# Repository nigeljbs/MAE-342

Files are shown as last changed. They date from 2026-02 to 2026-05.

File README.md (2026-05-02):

<p align="center">
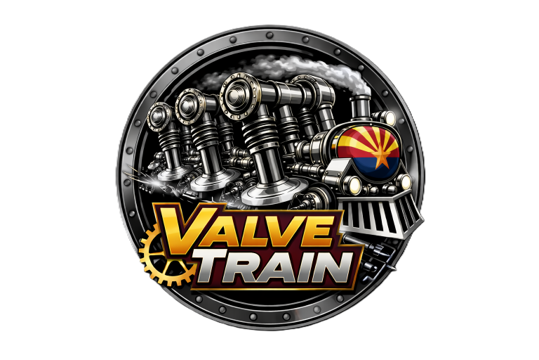
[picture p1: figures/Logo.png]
  
</p>

## Table of Contents
1. [Phase 1: System Understanding & Conceptual Design](Phase_1.md)
   
    [Phase 1 Video](https://youtu.be/j8frhQOj0eA)
2. [Phase 2: Detailed CAD Design & Engineering Analysis](Phase_2.md)
   
    [Phase 2 Video](https://youtu.be/f7b7LyeaBDE)
3. [Phase 3: Prototyping, Testing & Reflection](Phase_3.md)
   
    [Phase 3 Video](https://youtu.be/BKtHc9wmN2A)
4. [References](References.md)

*Please view all reports in a Light Theme*

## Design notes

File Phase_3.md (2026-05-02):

# Phase 3 - Prototyping, Testing & Reflection

<p align="center">
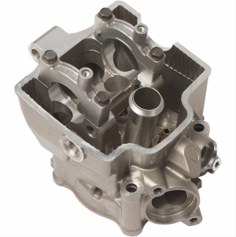
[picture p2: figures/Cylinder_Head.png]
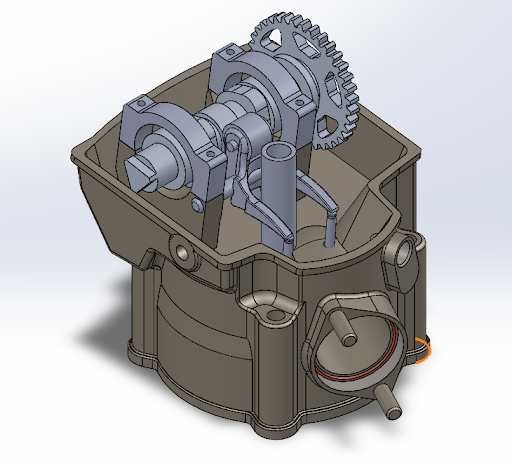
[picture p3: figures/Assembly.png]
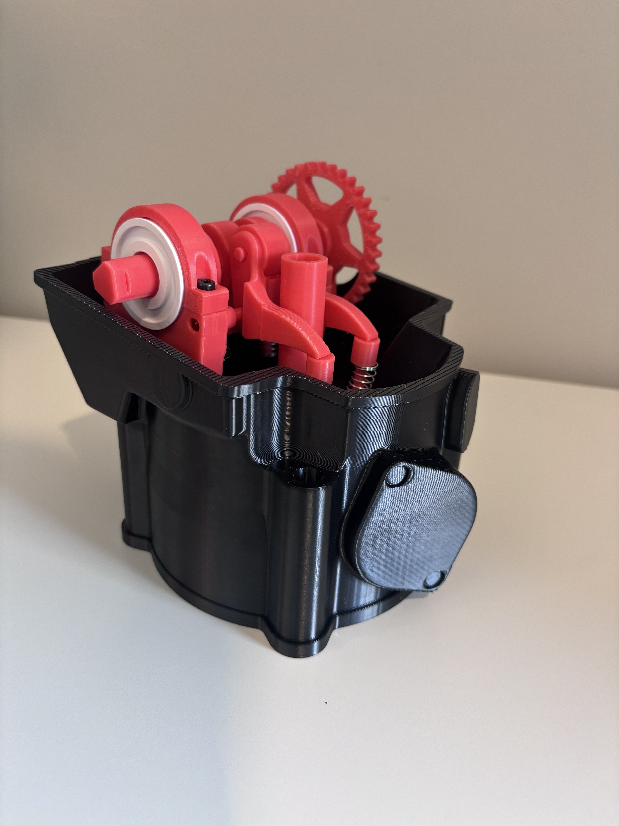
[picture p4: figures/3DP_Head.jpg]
     
</p>

## Fabrication Details
  Our valve train prototype was fabricated using PETG filament, brass threaded inserts, and springs. All 3D components were printed using PETG filament, which was selected for its balance of strength, durability, and ease of printing. A layer height of 0.16 mm, two wall loops, and 15% infill were used to obtain a balance between print efficiency and structural integrity. Supports were incorporated as needed, and the print orientation was strategically selected to maximize strength along primary load-bearing directions. The use of a relatively low infill density was justified by the Phase 2 analysis, which indicated that the system would not be subjected to significant structural loads. The brass threaded inserts and springs were sourced from McMaster-Carr.

<p align="center">
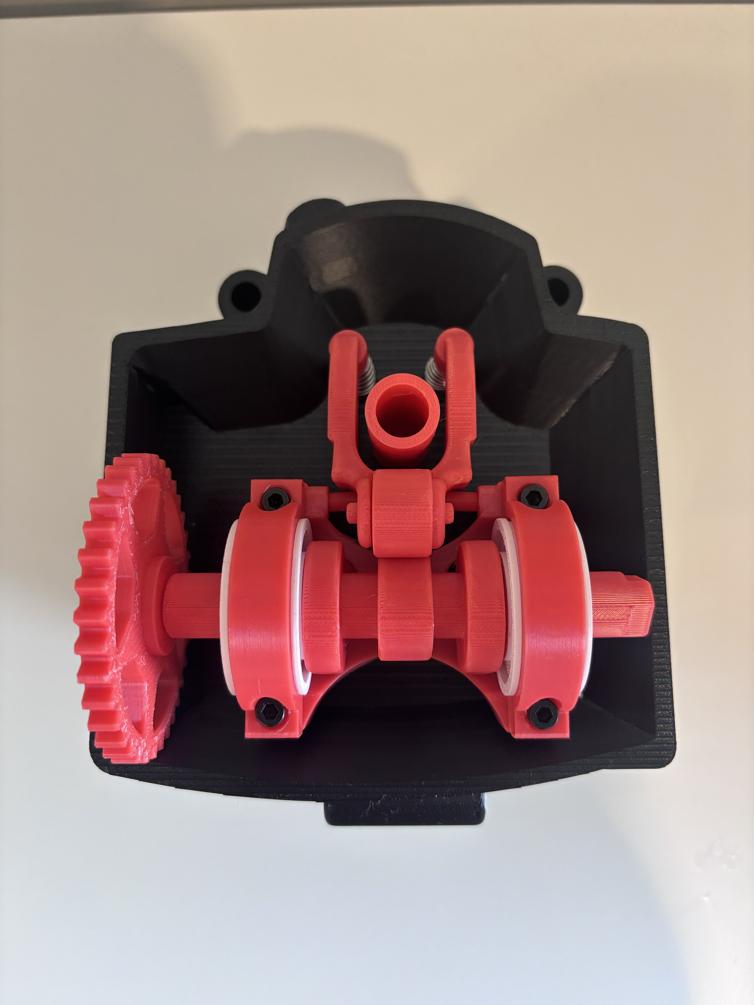
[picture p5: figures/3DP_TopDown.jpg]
  
</p>

## Assembly Procedure 
  The assembly process was completed as follows. The valves were first positioned within the cylinder head, followed by the installation of the valve buckets and springs. The rocker arm and roller were then mounted using pin connections. Finally, the camshaft was positioned in bearings, then the remaining structural components were secured using threaded fasteners. The modular design allowed certain components to be assembled into subassemblies before final integration, thereby reducing overall assembly complexity.
  
<p align="center">
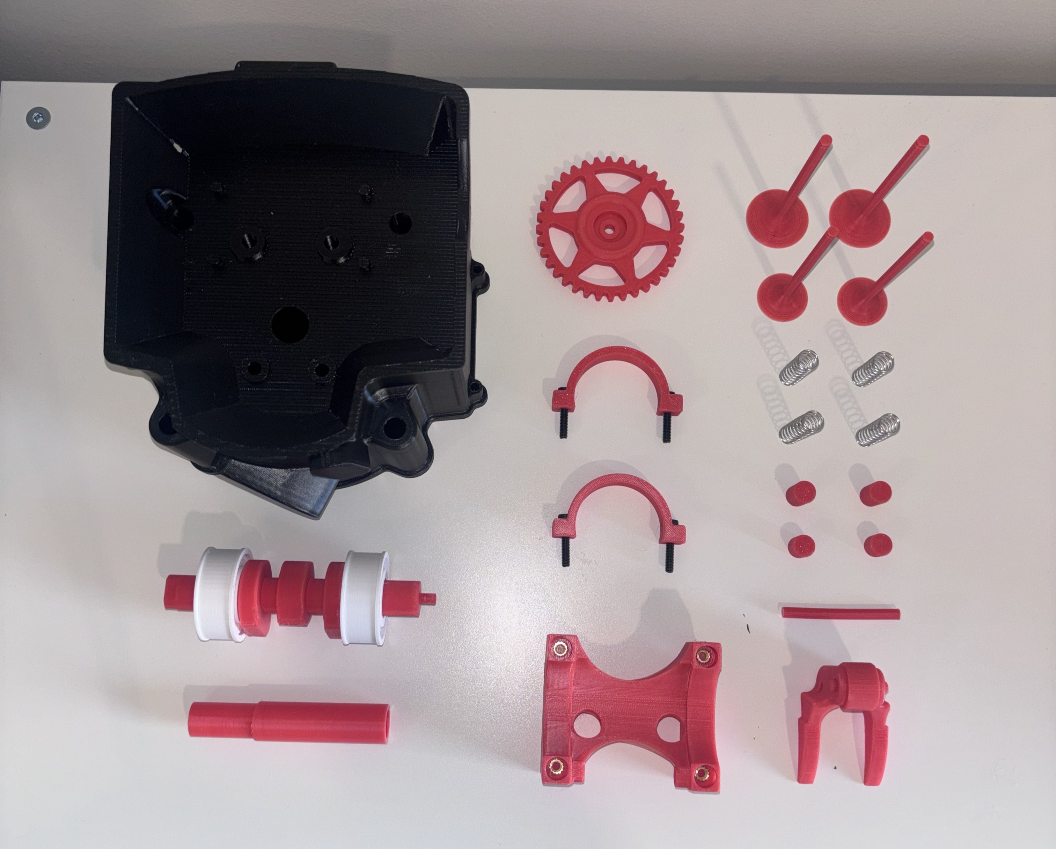
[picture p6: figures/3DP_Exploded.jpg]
  
</p>

<p align="center">
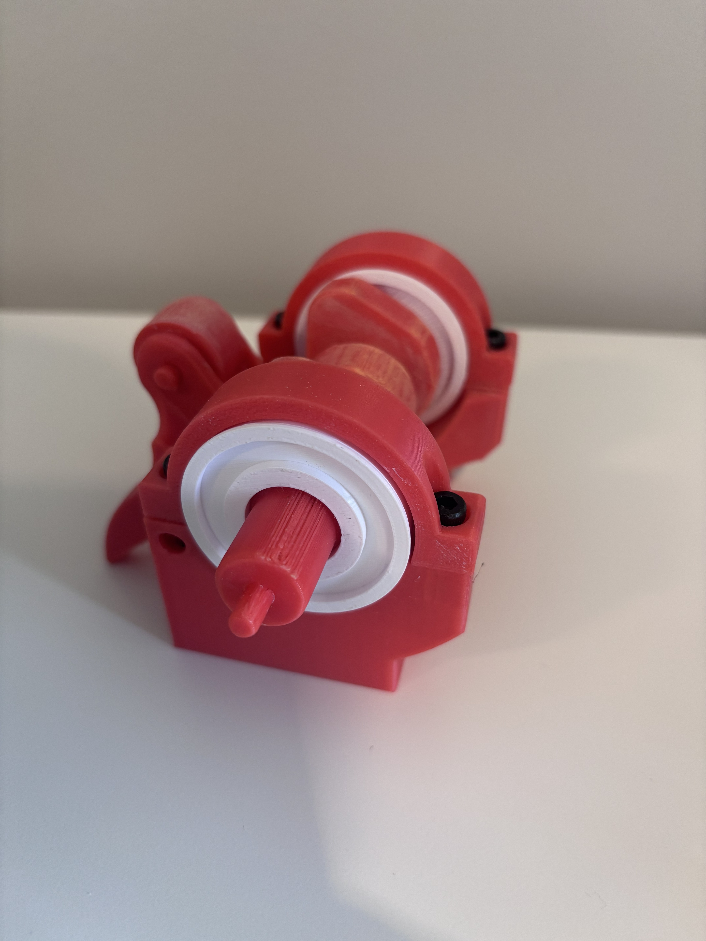
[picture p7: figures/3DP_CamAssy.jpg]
  
</p>

<p align="center">
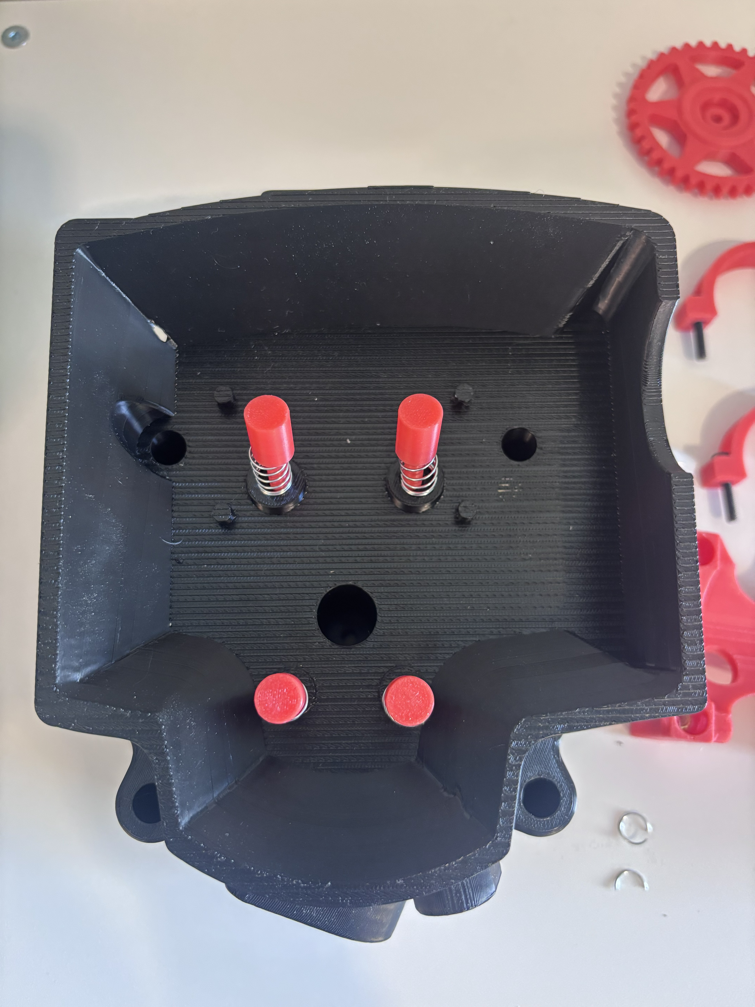
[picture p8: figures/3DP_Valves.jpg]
  
</p>

<p align="center">
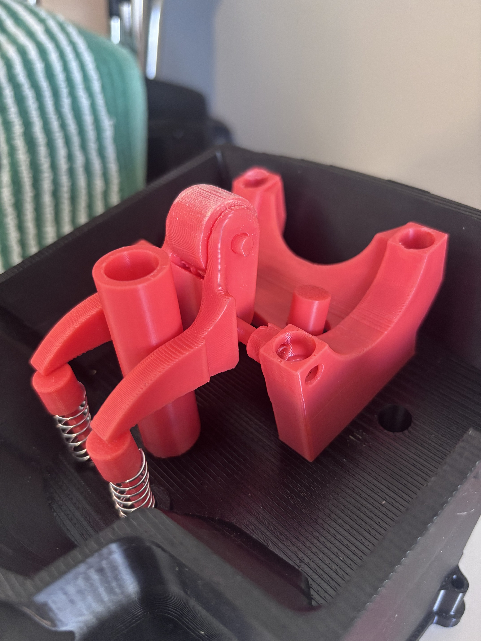
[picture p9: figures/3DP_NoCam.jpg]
  
</p>

## Test Procedures, Results, and Interpretation
  The prototype was evaluated by manually rotating the camshaft to simulate normal system operation. The objective of this test was to assess valve actuation, motion smoothness, and timing consistency. Observations were made through visual inspection, as well as by evaluating resistance and continuity throughout the motion cycle. The system successfully demonstrated the intended conversion of rotational input into both oscillatory and linear valve motion. Valve actuation followed the expected cyclic behavior dictated by the cam geometry, confirming the validity of the fundamental mechanism design. However, noticeable resistance was encountered during operation, and minor inconsistencies in valve motion were observed. These variations were primarily attributed to alignment issues and inconsistencies in part fit. The results indicate that, while the mechanism performs as designed in principle, real-world factors have a significant impact on performance. Friction at contact interfaces was higher than anticipated based on the Phase 2 analysis. The use of PETG introduced additional compliance, reducing overall stiffness and allowing minor deformation under load.

## Comparison with Phase 2 Predictions
 In phase 2, the system was evaluated under idealized assumptions, including rigid components, perfect alignment, and negligible friction. Experimental testing confirmed that the predicted motion behavior was generally accurate, as the system successfully achieved the intended valve actuation and timing sequence. However, several discrepancies emerged between the predicted and actual performance. The system exhibited greater frictional resistance than anticipated, which resulted in the motion being less smooth. In addition, its performance proved to be highly sensitive to assembly precision and alignment. These differences can be attributed to several factors. The material properties of PETG differ significantly from the idealized materials used in the analysis, particularly with respect to stiffness and anisotropic behavior. Dimensional variations introduced during the 3D printing process also affected component fit and alignment. Furthermore, key effects such as friction, wear, and deformation were not fully captured in the analytical model. While the Phase 2 analysis provided a valuable baseline for the design, the experimental results underscore the importance of accounting for real-world conditions in engineering predictions.

## Failures, Mistakes, and Surprises
  During testing, several issues were identified that adversely affected system performance. The major issue was with the first rocker arm. The arm would have too much deflection during cycling, which led to the arms not aligning properly with the exhaust valves. This was solved by increasing the size of the rocker arm as well as reducing the total spring force by cutting the springs down. Wear was observed at key contact interfaces, particularly between the cam lobes and their mating components, as a result of repeated loading and friction. Additionally, the material limitations of PETG introduce a risk of long-term deformation in load-bearing components. Some design and analysis shortcomings contributed to these outcomes. The effects of 3D printing tolerances on assembly and alignment were underestimated, leading to fitment challenges. Friction had a more significant impact on system performance than anticipated, and assembly precision proved to be critical for achieving smooth operation. Despite the relatively low infill, certain components performed adequately due to the modest loading conditions, which was originally expected.

<p align="center">
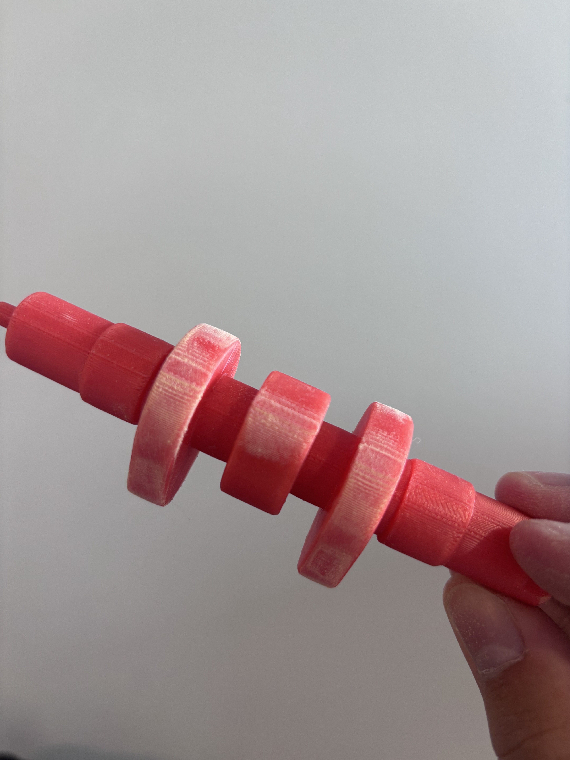
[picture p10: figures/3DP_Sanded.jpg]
  
</p>

<p align="center">
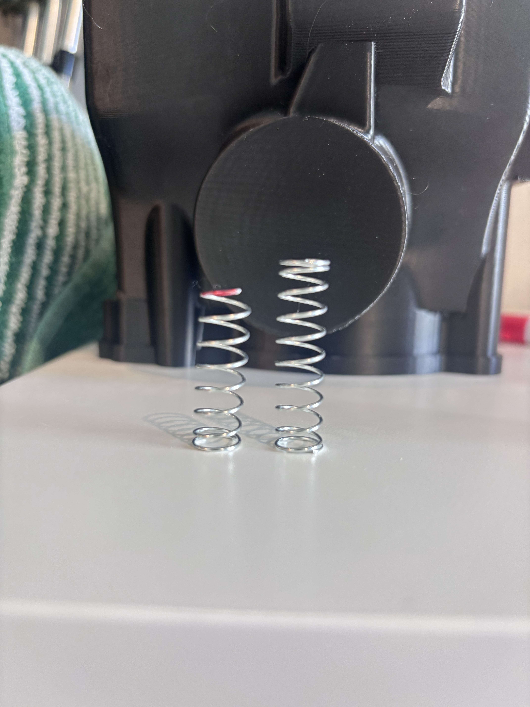
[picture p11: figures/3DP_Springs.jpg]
  
</p>

<p align="center">
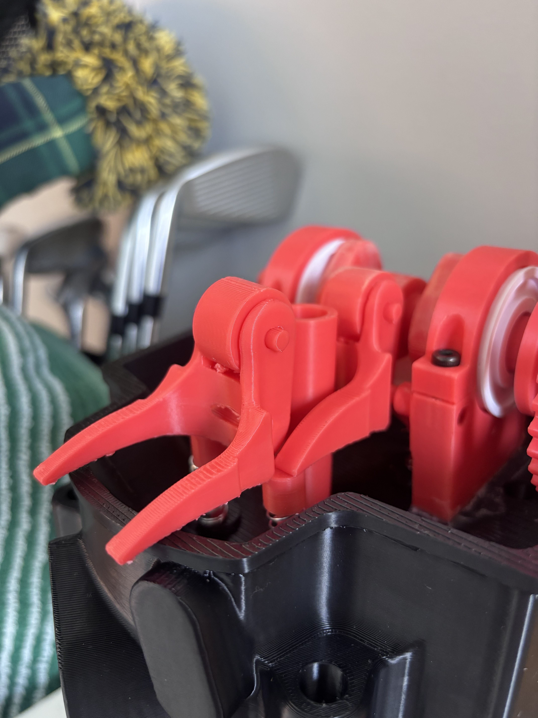
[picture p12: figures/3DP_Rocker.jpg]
  
</p>

## Design Improvements for Second Iteration
Based on the observed performance and identified issues, several improvements are recommended for a subsequent design iteration. Increasing infill density or wall thickness in high-stress and contact regions would enhance stiffness and reduce deformation. Dimensional tolerances should be refined to better account for the variability inherent in the 3D printing process, thereby improving component fit and alignment. Incorporating additional alignment features, such as guides or locating geometries, would promote consistent assembly and reduce sensitivity to installation errors. Frictional losses could be minimized through improved surface finishing or the application of lubrication at contact interfaces. Critical components may also benefit from the use of higher-strength materials or optimized print parameters to improve durability.

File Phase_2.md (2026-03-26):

# Phase 2 – CAD & Analysis

## Overview
  The final design consists of a mechanically actuated valve train integrated within a cylinder head assembly. The purpose of this system is to control the timing and motion of intake and exhaust valves through rotational input from a camshaft. This design converts rotational motion from the camshaft into oscillatory motion of the rocker, and finally into the linear motion of the intake and exhaust valves. 

  The system operates by rotating three separate cam lobes, of which one periodically contacts the rocker arm and the other two contact the intake valve buckets to cause linear motion, as well as a repeated cycle. Once the cam lobes contact either the rocker arm or the valve buckets, the corresponding valves are pushed down, and once the lobe is no longer making contact with the rocker arm, a restoring force provided by a spring is applied to the corresponding valves, which causes them to rise back to the starting position. This process repeats continuously, with valve actuation that is governed by the camshaft geometry to enable controlled airflow into and out of the cylinder. 

### CAD
<p align="center">
  
</p>

<p align="center">
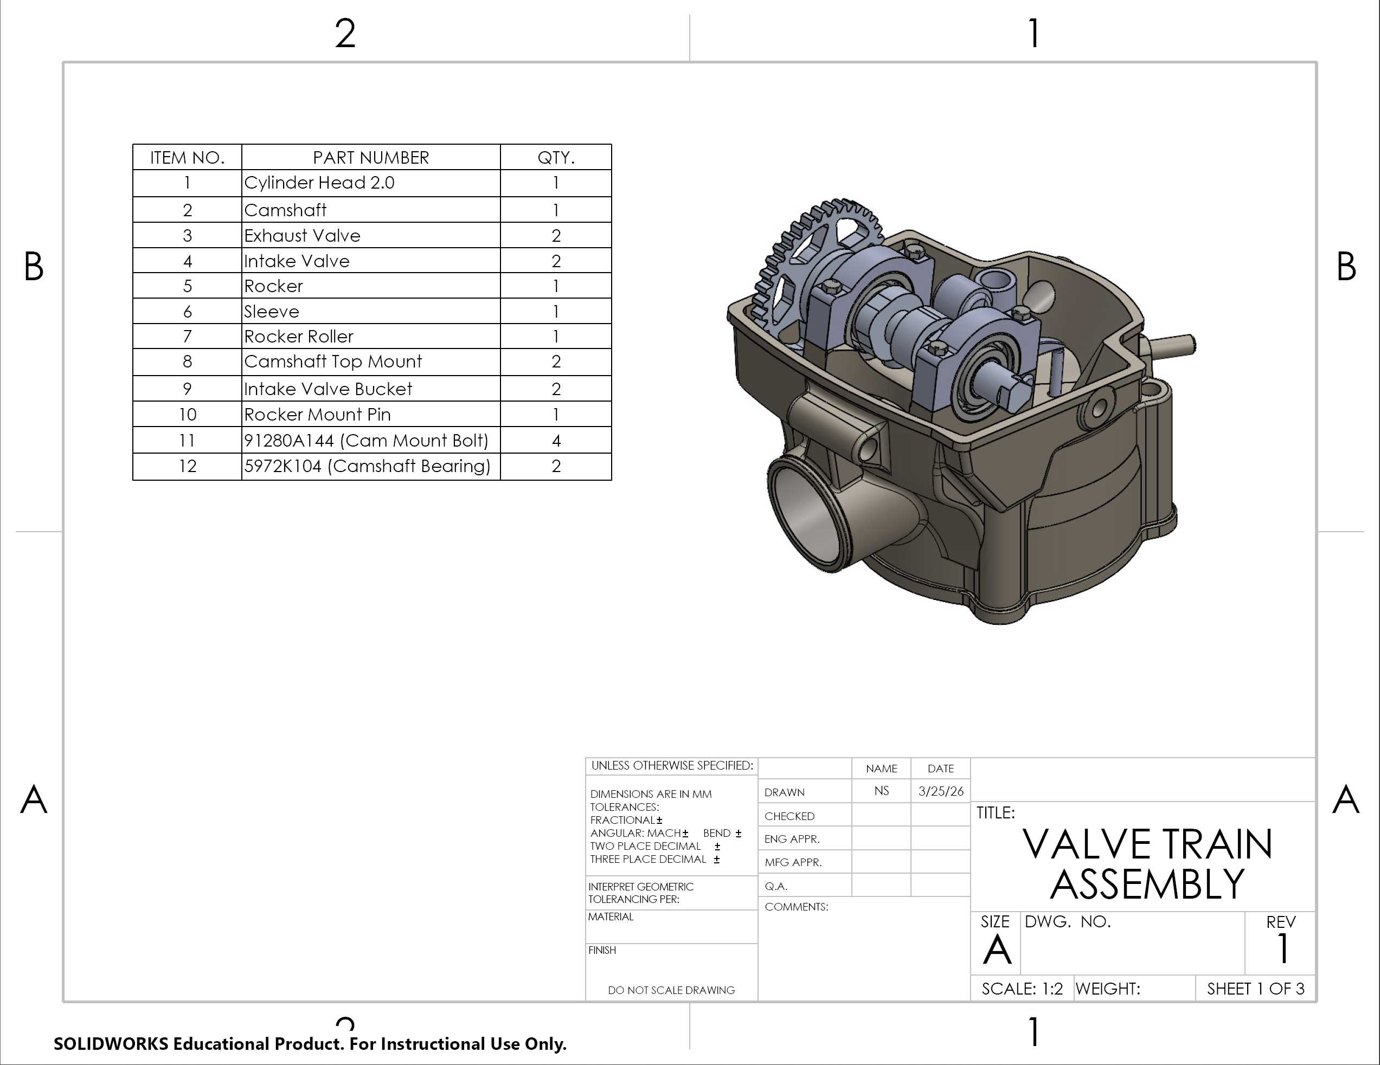
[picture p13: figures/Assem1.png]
  
</p>

<p align="center">
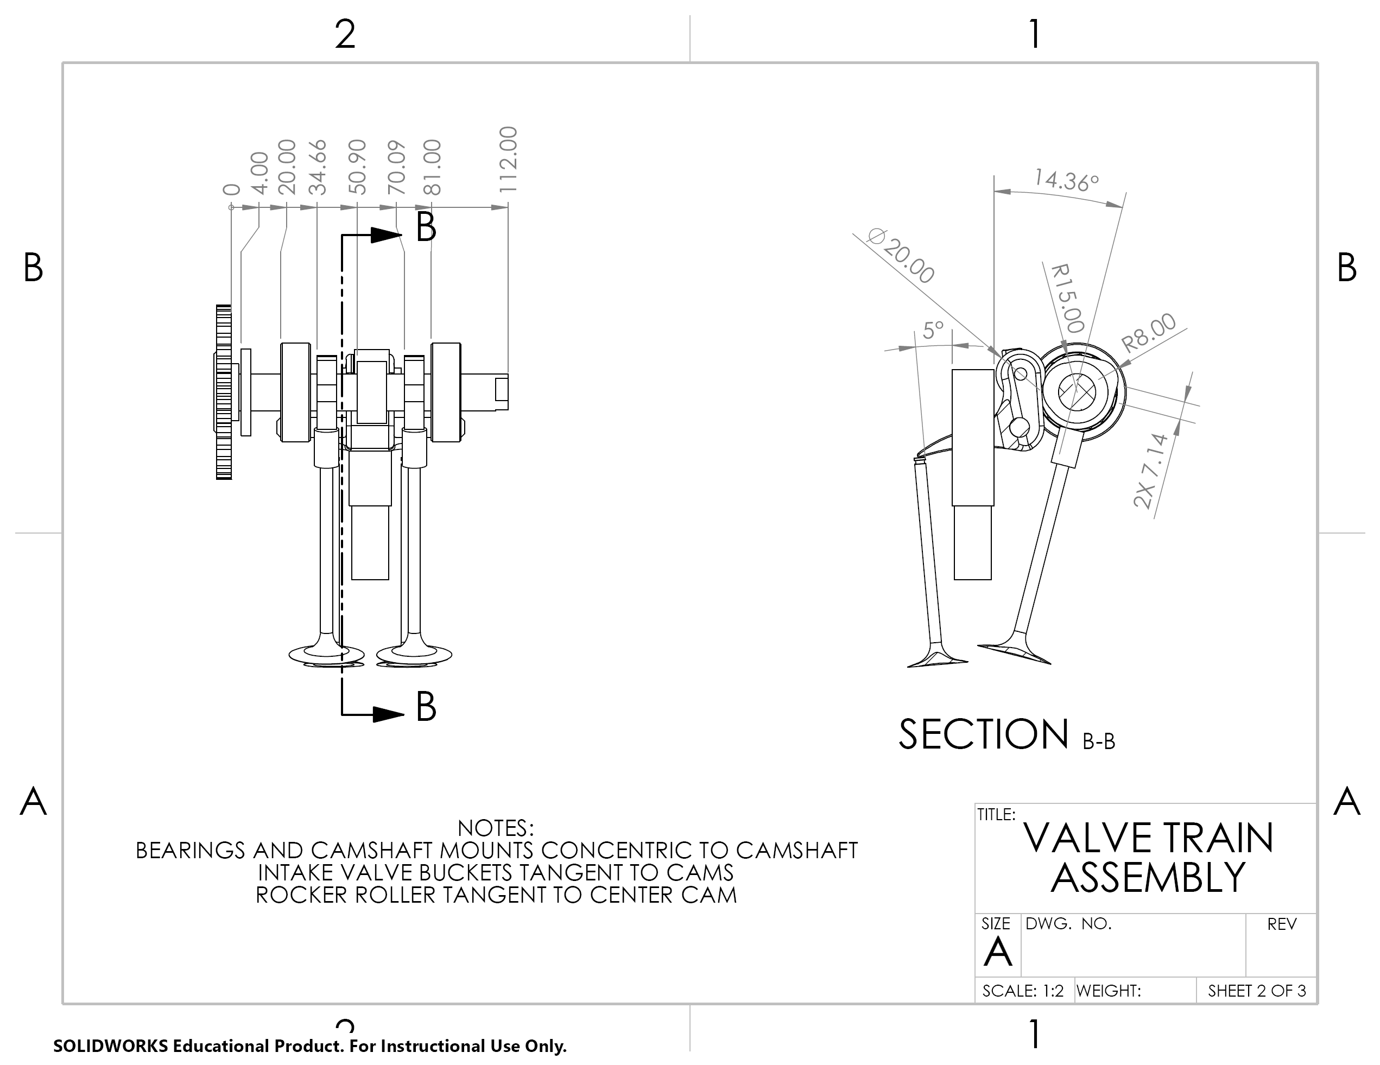
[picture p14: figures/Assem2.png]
  
</p>
<p align="center">
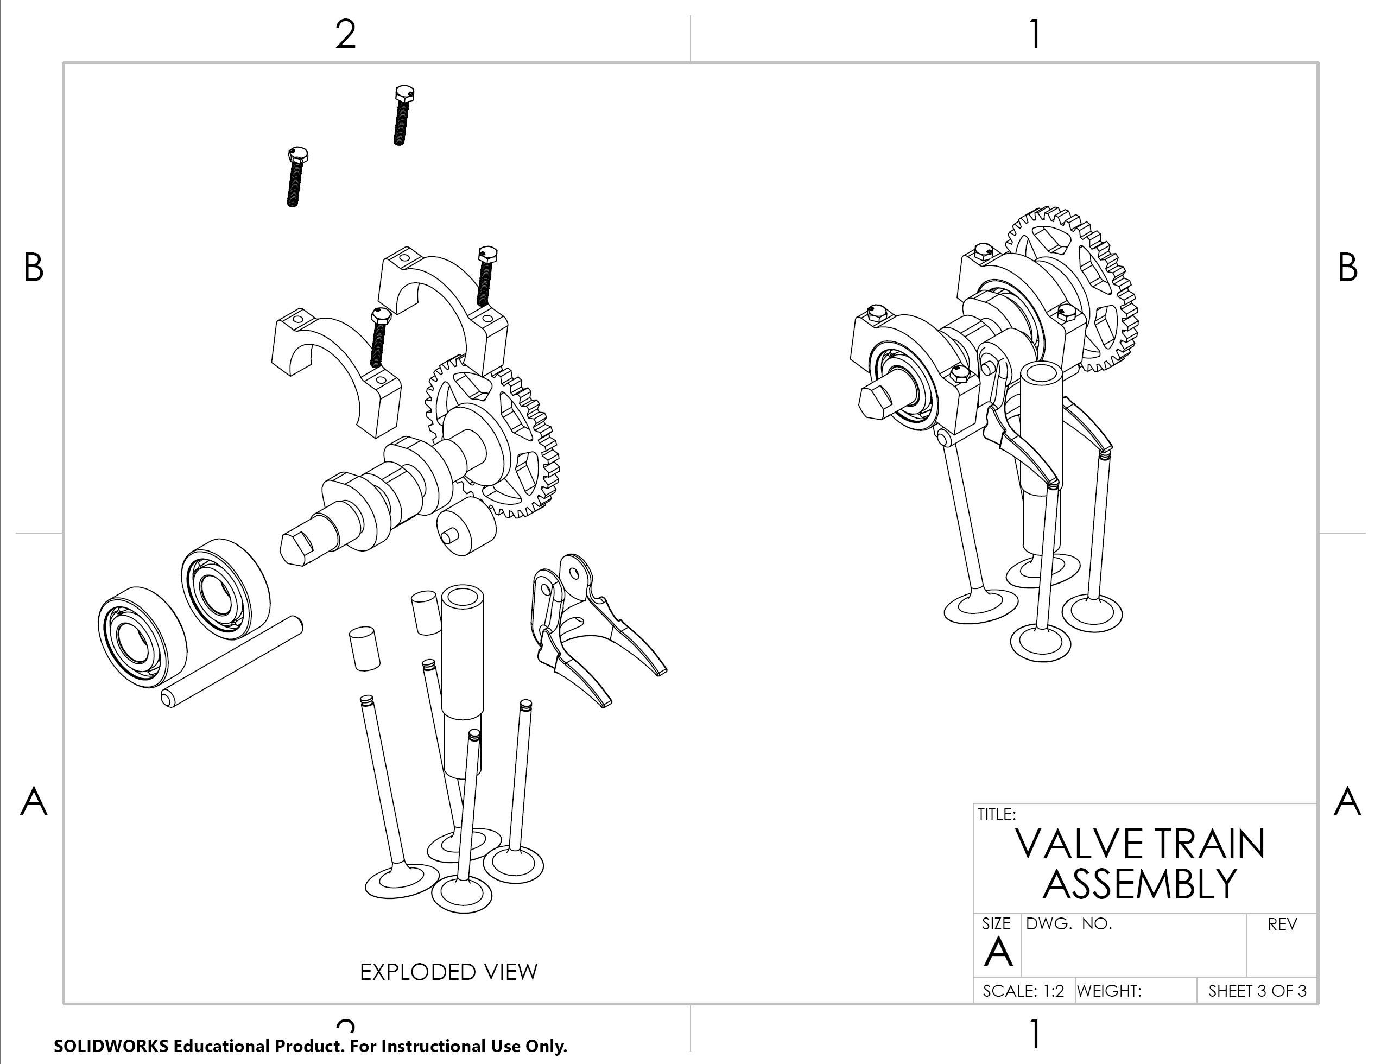
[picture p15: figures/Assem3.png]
  
</p>

### Analysis
Analysis performed in MathCAD
<p align="center">
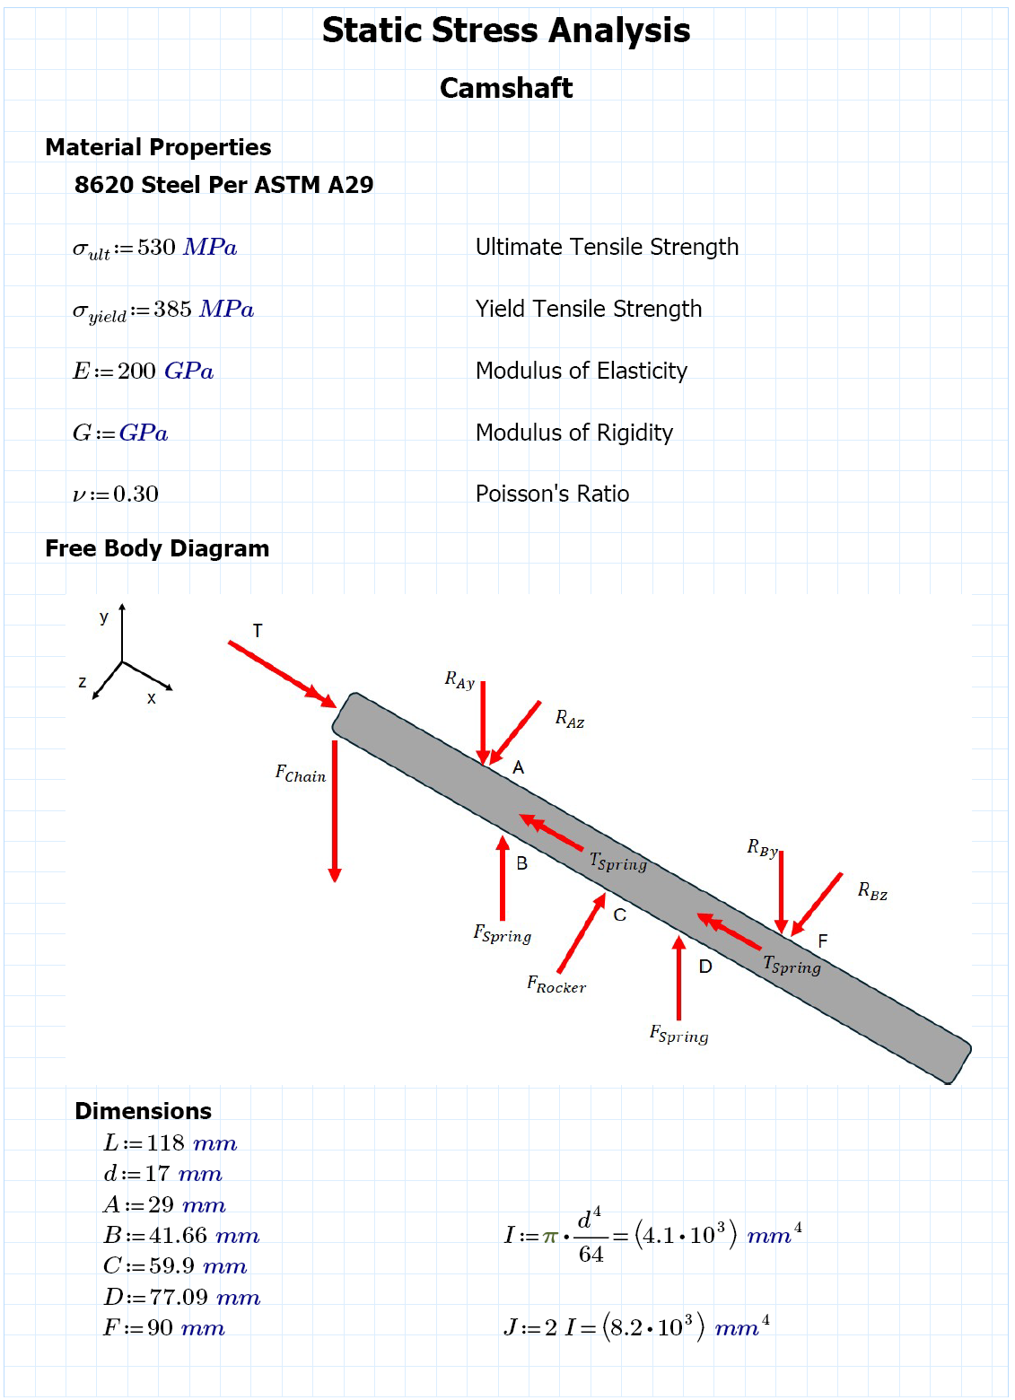
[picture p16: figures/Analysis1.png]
  
</p>
<p align="center">
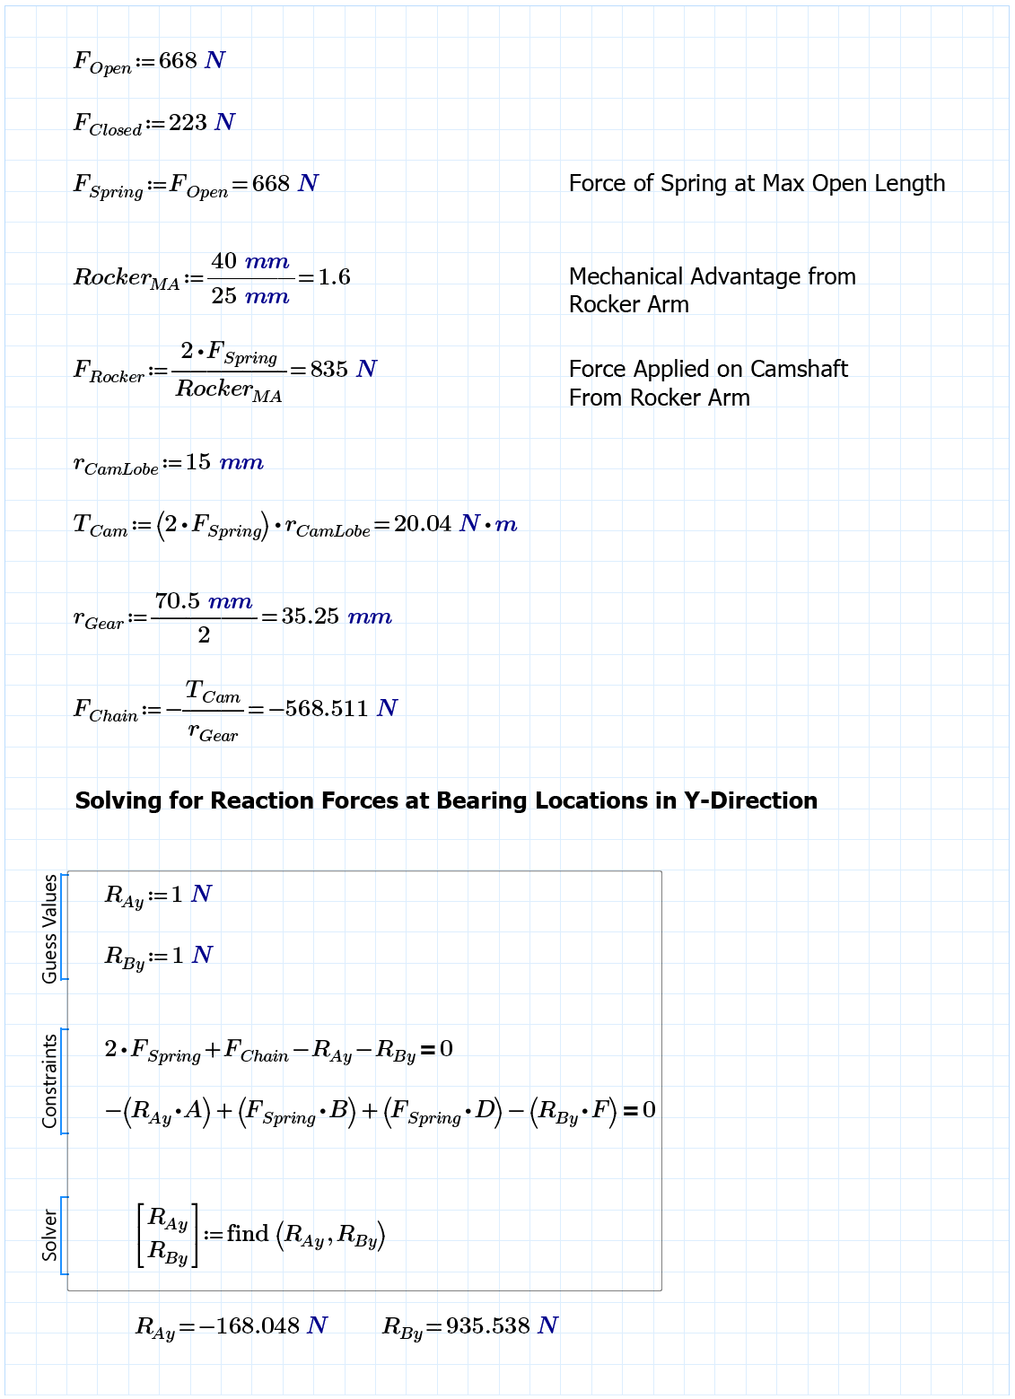
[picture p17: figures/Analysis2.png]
  
</p>
<p align="center">
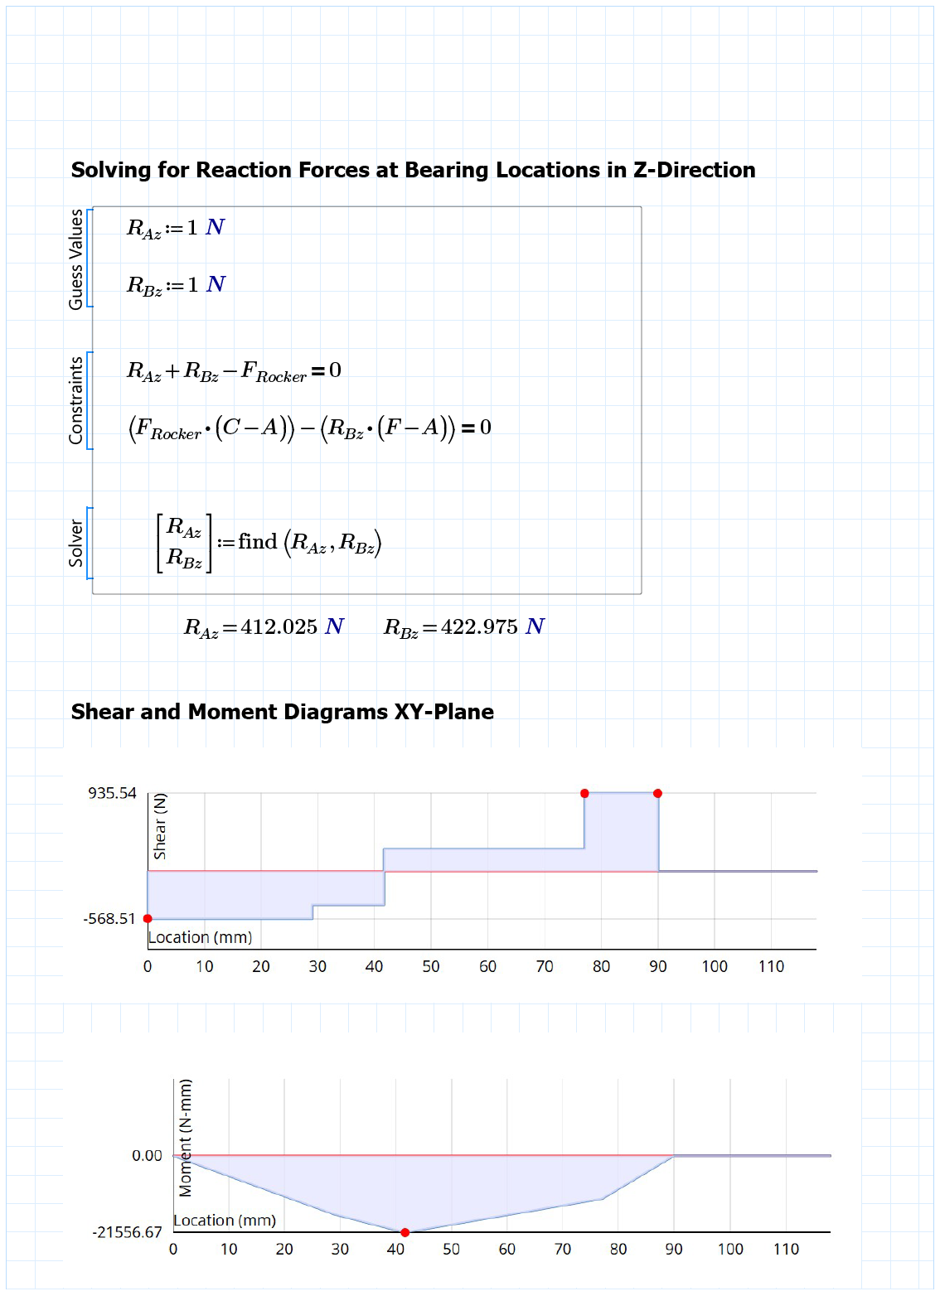
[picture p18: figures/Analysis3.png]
  
</p>
<p align="center">
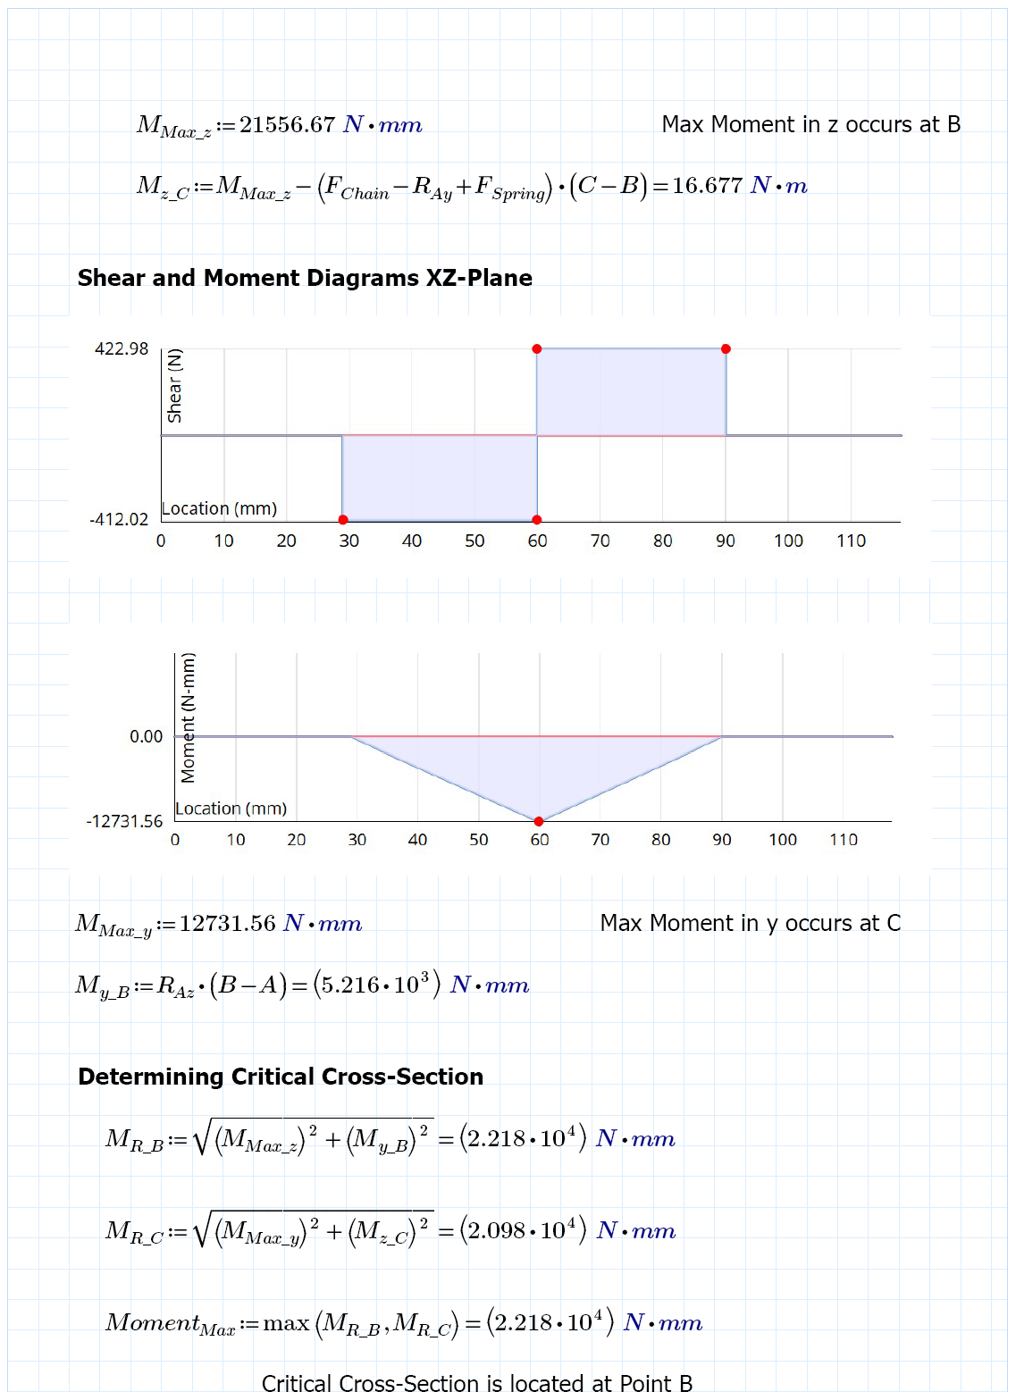
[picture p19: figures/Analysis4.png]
  
</p>
<p align="center">
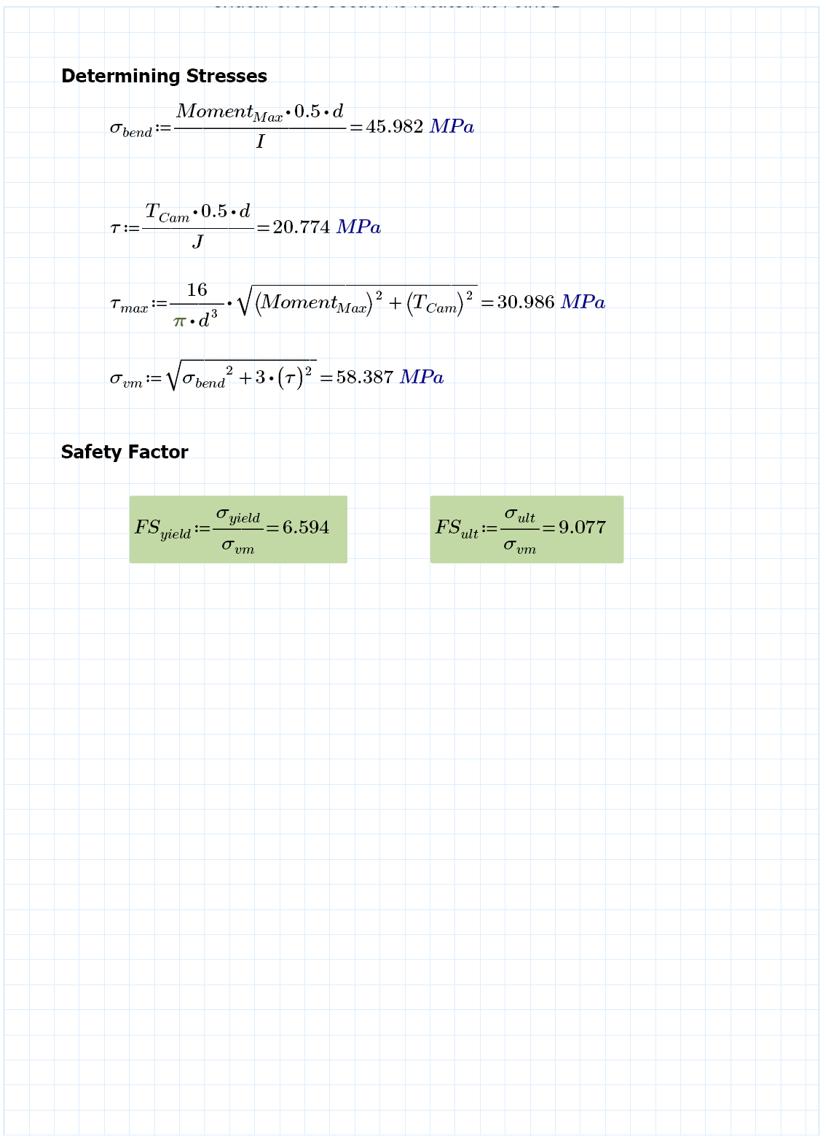
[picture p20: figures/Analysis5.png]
  
</p>
<p align="center">
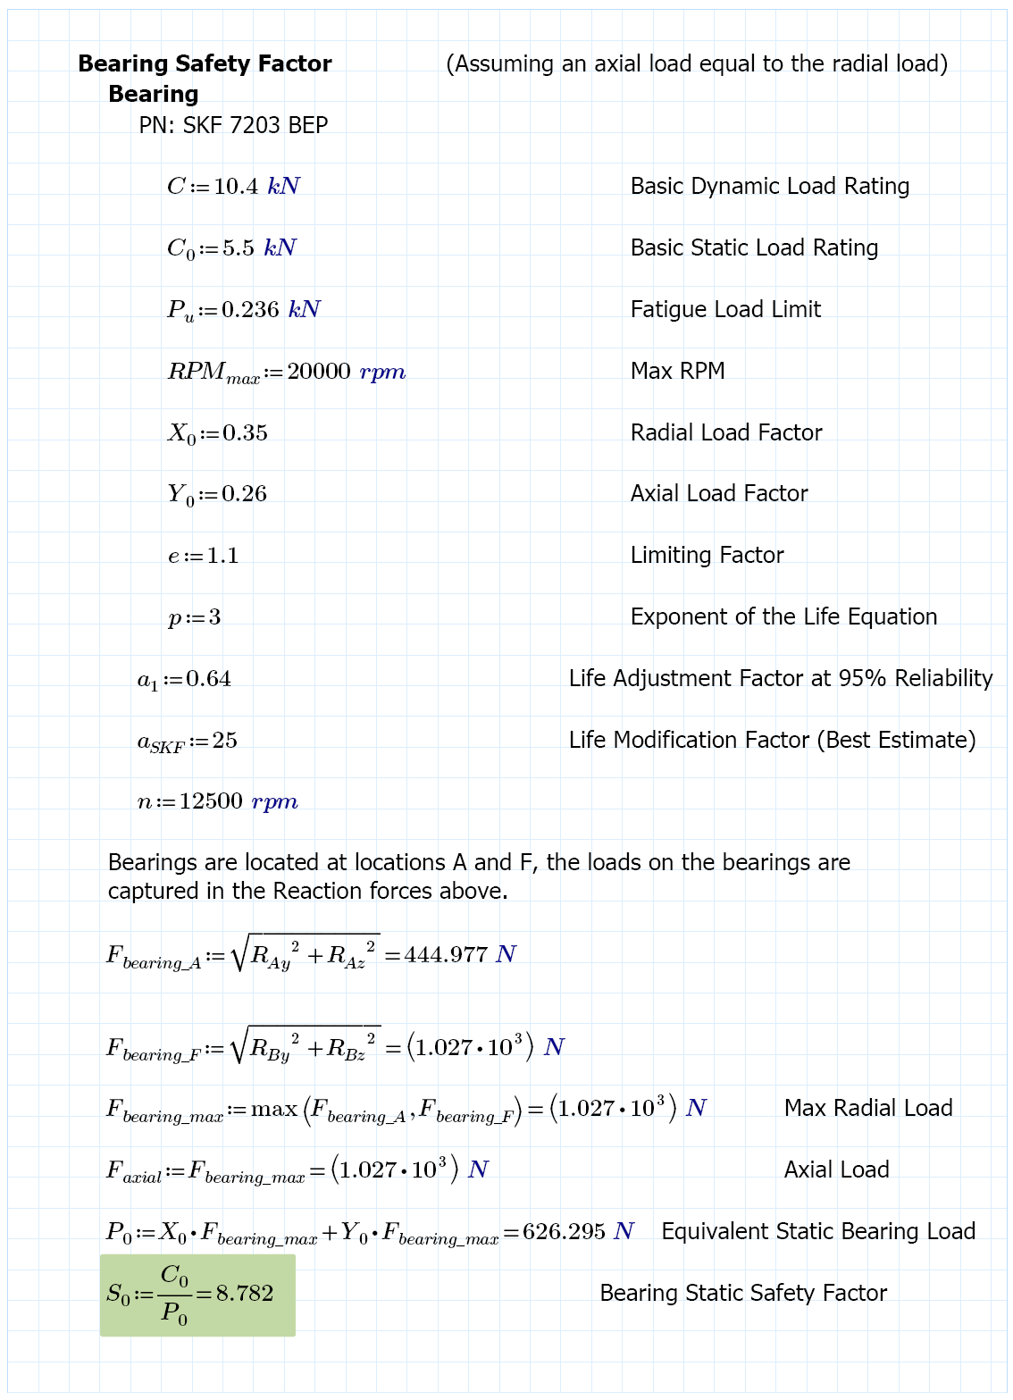
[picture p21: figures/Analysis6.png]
  
</p>
<p align="center">
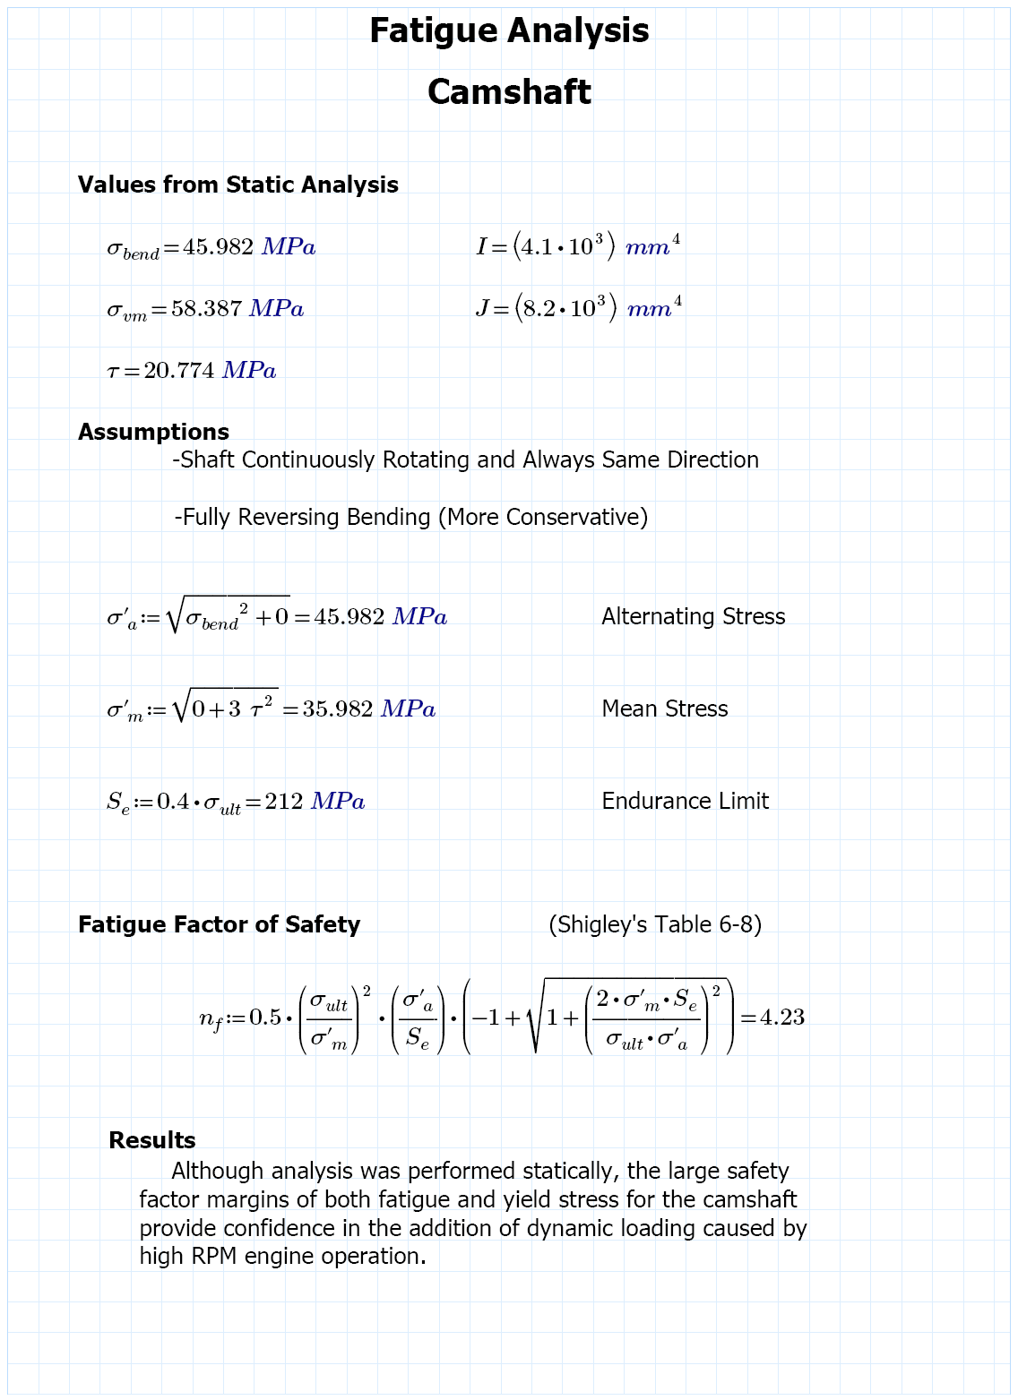
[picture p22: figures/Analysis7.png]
  
</p>
<p align="center">
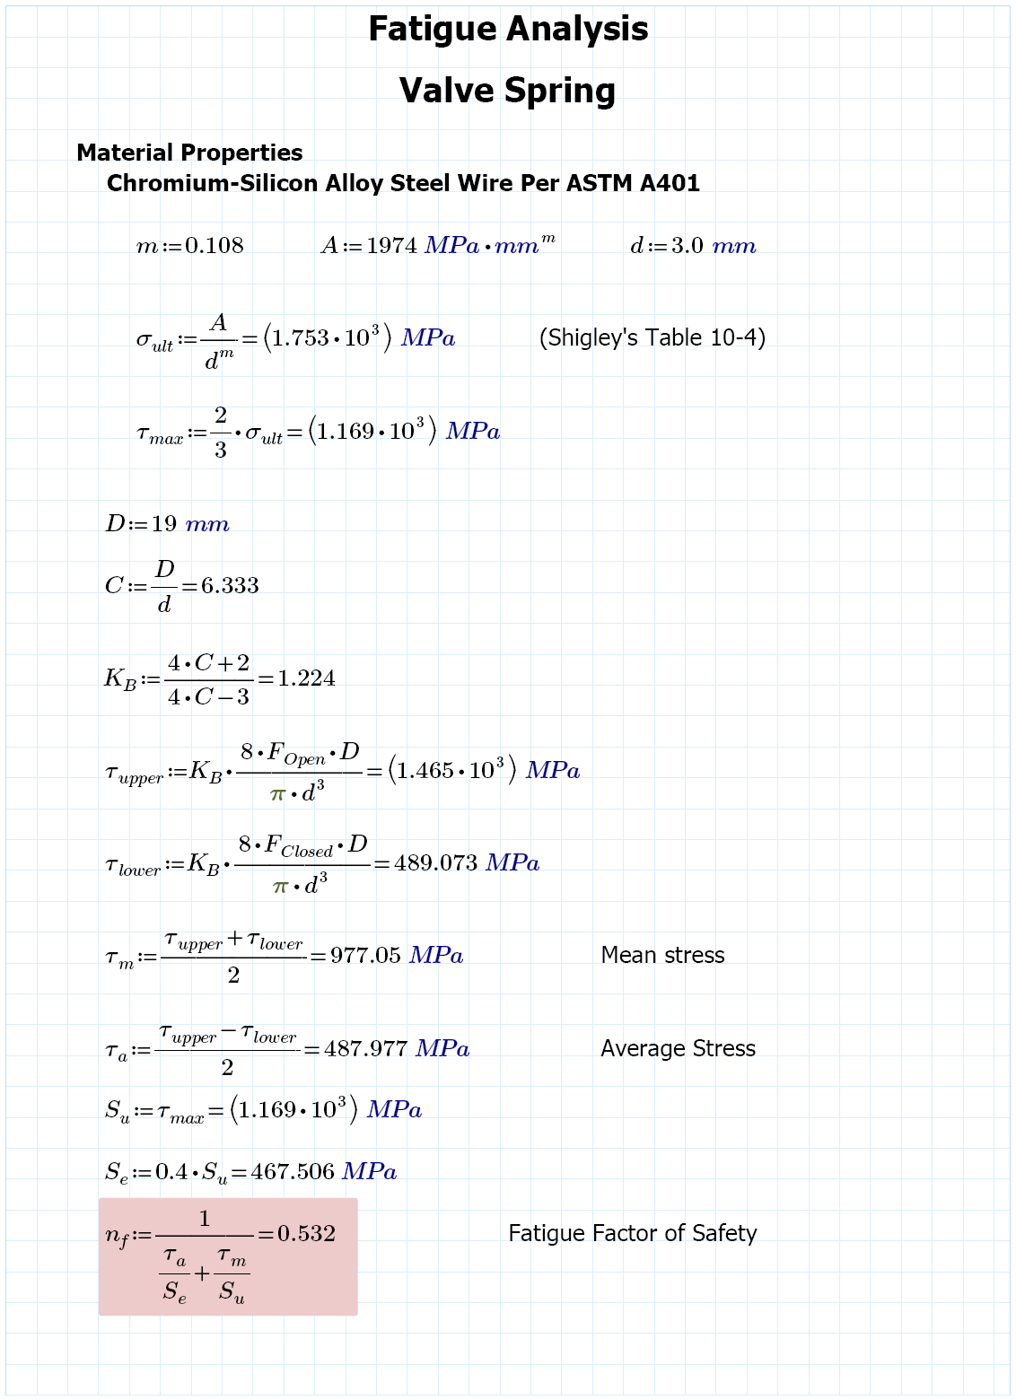
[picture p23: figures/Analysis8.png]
  
</p>
<p align="center">
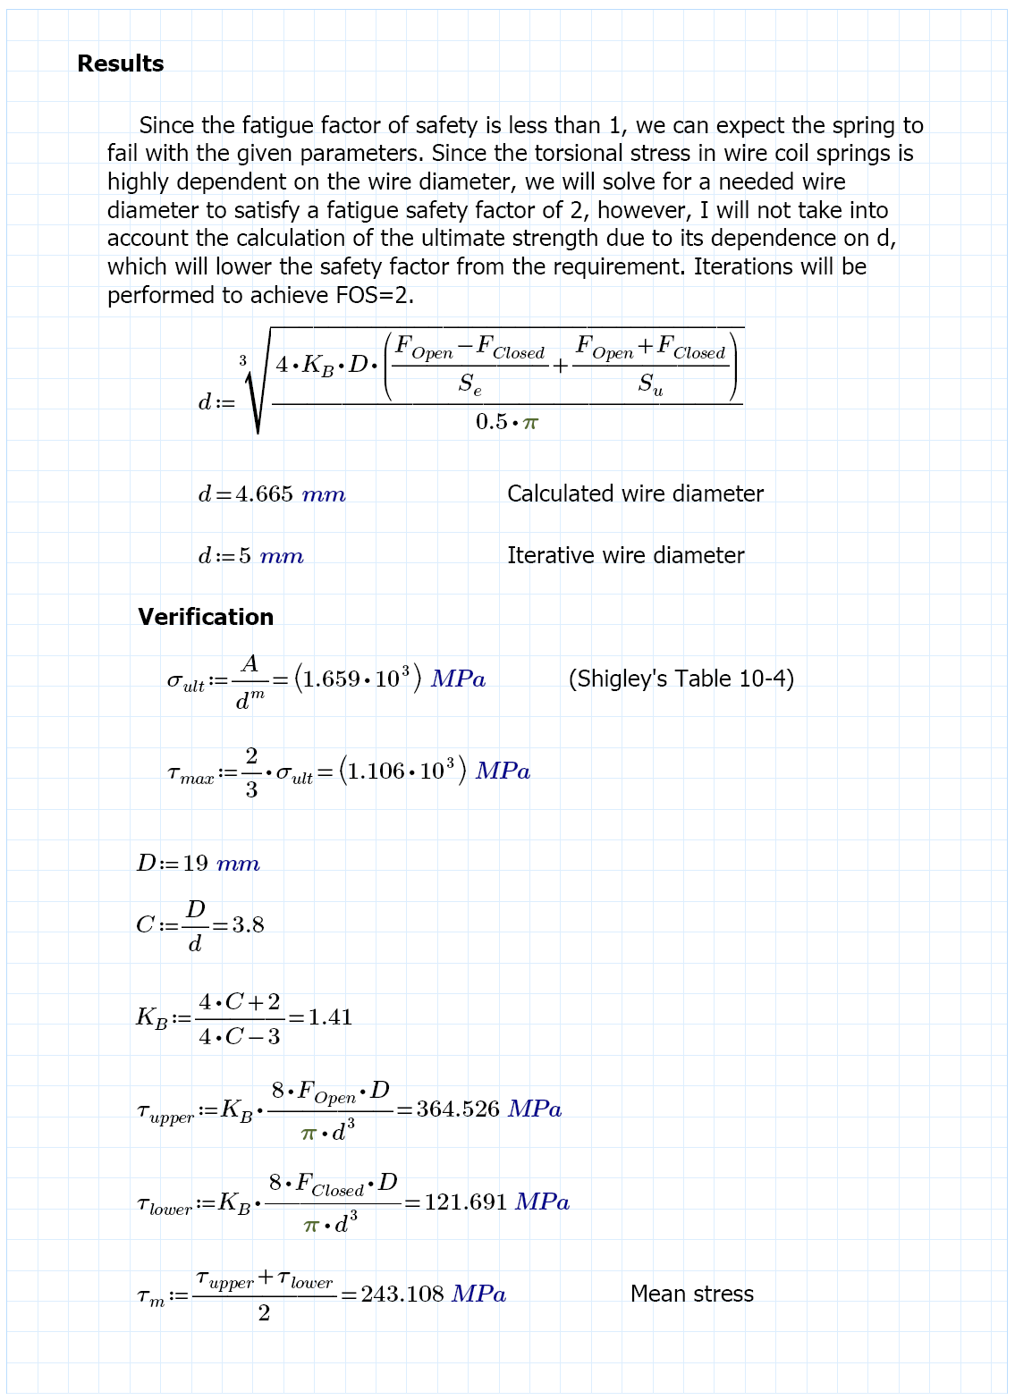
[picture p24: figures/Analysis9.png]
  
</p>
<p align="center">
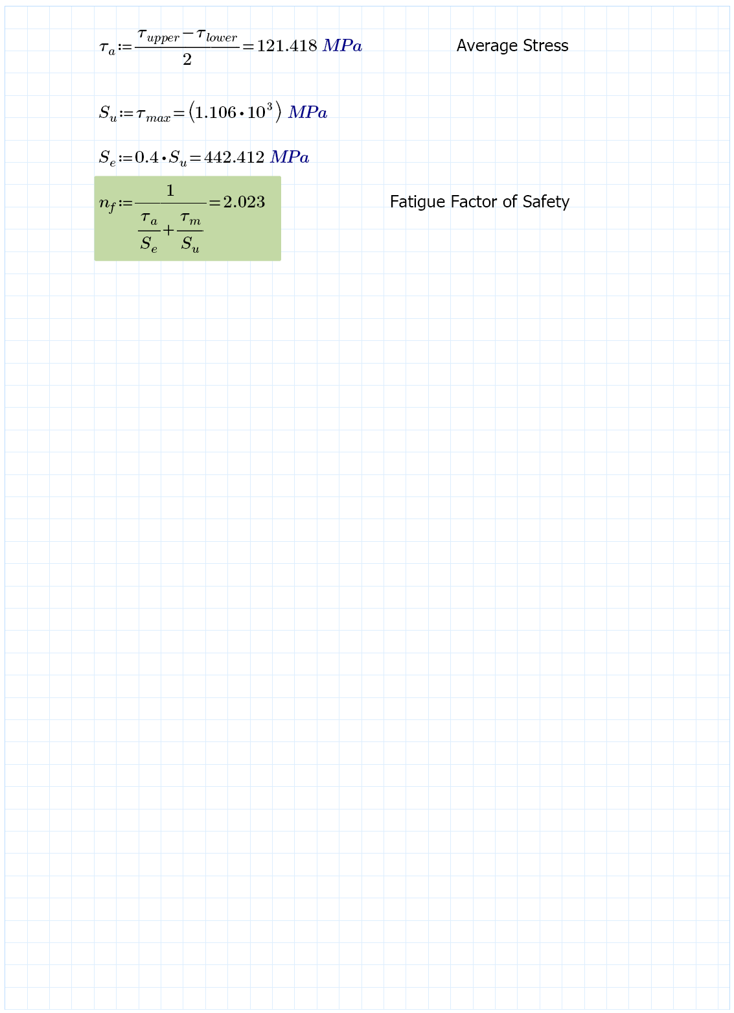
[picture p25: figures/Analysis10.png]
  
</p>
---

### Discussion of design for assembly and design for 3D printing
Design for Assembly
The valve train system was designed with a focus on simplicity and modularity. Components such as the camshaft, rocker arm, roller, and valves are arranged along a primary shaft, allowing for a straightforward, sequential assembly process. Pin-based connections enable rotational motion while keeping interfaces simple and easy to install or remove.
Threaded connections are reinforced using brass inserts with stainless steel fasteners, improving durability and preventing thread wear in printed parts. The design also supports subassembly of smaller components before final integration, reducing overall assembly complexity. A key limitation is the reliance on proper alignment between moving components, particularly at the camshaft and rocker interface. Misalignment or improper installation of small components such as pins and rollers may lead to increased friction or binding.
Design for 3D Printing
All components are designed for FDM 3D printing using PETG with a 0.16 mm layer height, two wall loops, and 15% infill. These settings provide a balance between print efficiency and sufficient strength for prototyping. The calculated bending stress is well below the material yield strength, indicating the design is not highly loaded.
However, 3D printed parts exhibit anisotropic behavior, making print orientation critical for strength in load-bearing components. The relatively low infill may reduce stiffness, particularly near contact regions such as the cam–roller interface. Additionally, print tolerances and surface finish may require minor post-processing to ensure smooth operation. The use of brass threaded inserts improves the reliability of fastened connections, making the design more suitable for repeated assembly and use.

Updated list of anticipated risks or weaknesses:

Material Used:

With the usage of PETG, the difference in strength and stiffness for PETG compared to Metal, poses a risk of deformation of the model with repeated testing. As well as friction or lubrication causing our material to be worn down over time due to the other model components. This causes the model's structural integrity to decline and deform over time, which affects our critical points that can lead to the fracture of our model.

Printing Errors:

Due to 3D printing not always being precise, we could run into issues regarding the stability and failure risk of our model. Due to the infill or layering issues, our print must not have any structural imperfections. Especially in high stress areas, any minor 3D printing issue can cause our model to fracture or simply not work. We must ensure our 3D print has tolerances which allow all parts to fit, which ensures the parts don’t come into contact with one another causing friction, or simply aren’t too loose to cause vibrations.

Components used:

With using springs, we run into the issue that cyclic loading of the valve springs can lead to fatigue and eventual failure, reducing their ability to properly control the valves. Spring failure may cause gear wear and misalignment of the camshaft. Our valve float always runs the risk of our valve springs not being able to close the valve fast enough at high RPMs, which causes loss of contact with the cam lobe and potential valve-to-piston contact. Also our cam lobe can have high contact stresses between the cam lobe and follower or rocker interface can lead to surface fatigue, pitting, or scuffing, especially under inadequate lubrication or high spring loads. This wear alters the cam profile over time, reducing effective valve lift and changing valve timing. In severe cases, material loss can accelerate further wear and lead to catastrophic valvetrain failure.

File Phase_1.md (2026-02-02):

# Phase 1 – System Understanding and Conceptual Design

## Executive Summary
This report examines how a Unicam-style overhead cam valve train system works, its key components, and potential failure points. The valvetrain is a critical component in a four-stroke engine assembly, as it controls the timing and motion of the intake and exhaust valves. The valves regulate the air-fuel mixture entering the combustion chamber and the exhaust gases leaving it.  

In this specific system, a single camshaft operates directly on the intake valves while using a rocker to actuate the exhaust valves, allowing for precise valve timing with fewer moving parts. This design reduces inertia in the valvetrain, helping prevent valve float at high engine speeds and improving overall engine efficiency.

### Four-Stroke Engine Overview

A four-stroke engine completes a power cycle in four distinct strokes of the piston: intake, compression, combustion, and exhaust.

1. **Intake Stroke:** The intake valve opens, and the piston moves down the cylinder, drawing in the air-fuel mixture.  
2. **Compression Stroke:** Both valves are closed, and the piston moves up, compressing the mixture to increase pressure and temperature for efficient combustion.  
3. **Combustion Stroke:** The spark plug ignites the compressed mixture, forcing the piston downward and generating torque on the crankshaft.  
4. **Exhaust Stroke:** The exhaust valve opens, and the piston moves up again, expelling the spent gases from the cylinder.  

This cycle repeats for each cylinder, with the camshaft coordinating valve opening and closing so that intake and exhaust events occur at the correct crank angles. In multi-cylinder engines, the strokes are staggered to ensure smooth power delivery. 
<p align="center">
  
</p>

---

## System Function and Decomposition
**Overall function:** Convert crankshaft rotation into precisely phased valve motion (lift, dwell, and seating) to control cylinder air exchange (intake and exhaust) during the four-stroke combustion cycle. The valvetrain ensures that intake valves open at the correct moment to admit the optimal air-fuel mixture and close in time to maximize compression efficiency. Simultaneously, exhaust valves open to release combustion gases efficiently, minimizing residual heat and preventing backflow.  

This precise timing is critical at high engine speeds, where even slight deviations can reduce volumetric efficiency, cause valve float, or create interference with piston motion. The Unicam design allows a single camshaft to directly actuate the intake valves while using a rocker arm to drive the exhaust valves, reducing moving mass and inertia in the system. By controlling lift profiles, dwell periods, and seating forces, the system maintains engine performance, durability, and efficiency across the full operating range, including operating speeds up to 13,000 RPM, while minimizing wear and the risk of component failure.

The images below show a CRF250 cylinder head with arrows identifying the key components of the valvetrain.  

- The first image shows the fully assembled cylinder head, illustrating how the camshaft, valves, rocker arms, and other components fit together in the system.  
- The second image shows the disassembled valves, including valve springs, valve buckets, and guides, as well as the rocker.  
- The third image focuses on the assembled valves and their associated components, showing the direct contact points between the cam, rocker, and valves.  

These visual aids help to understand the layout and interactions of the components, as well as the paths of motion through the valvetrain during operation.

<p align="center"> 
   
</p>

<p align="center">
  
</p>

<p align="center">
  
</p>

---

## Component Breakdown
| Component | Image |
|:---|:---|
| **Cylinder Head**  
This component provides the structural support and alignment for the camshaft bearings, valve guides, and rocker arm pivots. |  |
| **Camshaft**  
Controls valve timing and lift. Intake valves are directly actuated via cam–follower contact, while exhaust valves are actuated through cam–rocker contact. |  |
| **Rocker Arm**  
Transfers cam motion to the exhaust valves, allowing a more compact system layout. |  |
| **Valves**  
Intake valves allow the air–fuel mixture in, while exhaust valves release combustion gases. Valves are subjected to repeated impact loading, bending, and high-cycle fatigue. |  |
| **Valve Springs**  
Close the valve after cam actuation and maintain follower contact. Made from chrome-silicon steel for fatigue resistance at high RPM. |  |
| **Valve Guides**  
Maintain valve alignment and facilitate heat transfer to the cylinder head. Excessive wear can cause oil consumption and poor sealing. |  |
| **Valve Bucket (Follower)**  
Transmits cam motion while reducing friction and wear; maintains proper lift and alignment in the valvetrain. |  |
| **Timing Chain**  
Synchronizes camshaft and crankshaft motion, using guides and a tensioner to maintain proper tension and reduce vibration. |  |
| **Camshaft Bearings**  
Support the camshaft and transfer loads to the cylinder head, reducing friction and ensuring smooth rotation at high RPM. |  |

---

## Kinematics
Kinematics describes how rotational input at the crankshaft produces cam motion and valve lift. For a four-stroke engine, each cylinder completes one intake and one exhaust event every two crank revolutions.

### Cam Profile and Follower Motion

The cam profile defines the motion of the valve over time, controlling lift, dwell, and seating. The follower (direct-acting or rocker-actuated) translates the cam lobe's rotation into linear valve motion.  

Key points:  
- The **base circle** represents the minimum lift of the valve.  
- The **rise segment** determines how quickly the valve opens.  
- The **dwell** at peak lift ensures maximum air-fuel flow or exhaust clearance.  
- The **fall segment** controls valve closing.  

The follower can be a **flat tappet, roller, or bucket type**, and its motion may be scaled by a rocker ratio if the cam drives a rocker arm.  

<p align="center">
  
</p>

### Camshaft Speed Relationship (Four-Stroke)
The camshaft rotates at half the crankshaft speed: `omega_cam = 0.5 * omega_crank`.  
This is achieved via the timing drive (sprocket tooth ratio or gear ratio), so the cam completes one revolution per 720° of crank rotation. If the sprocket teeth are known, the ratio can be expressed as: `omega_cam / omega_crank = N_crank / N_cam`.
Where N = Number of teeth

### Valve Lift
Valve lift is determined by cam lobe geometry and the follower/rocker mechanism:

- **Direct-acting follower:** `L_valve ≈ L_cam`  
- **Rocker-actuated valve:** `L_valve ≈ R * L_cam`, where `R = (rocker output lever) / (input lever)`

> For Phase 2, peak valve acceleration and spring force checks may be needed. Compute follower displacement from the cam profile, then differentiate to get velocity and acceleration versus cam angle.

### Key Kinematic Checks
- Confirm timing: intake opens/closes, exhaust opens/closes at intended crank angles.  
- Ensure maximum valve lift meets flow requirements without coil bind or retainer/guide interference.  
- Check valve-to-piston clearance at overlap and near TDC on compression.  
- Evaluate valve float risk at target RPM (based on spring rate, mass, acceleration).  
- Confirm lash (clearance) range accounts for thermal growth and wear.

---

## Preliminary Failure Mode Review

### Spring Fatigue
Over long periods, cyclic loading of the valve springs can lead to fatigue and eventual failure, reducing their ability to properly control the valves. Spring failure may cause gear wear and misalignment of the camshaft.  

**Mitigation:** Use springs with improved cyclic loading properties or replace/repair routinely.  

<p align="center">
  
</p>

### Valve Float
Occurs when valve springs cannot close the valve fast enough at high RPMs, causing loss of contact with the cam lobe and potential valve-to-piston contact.  

**Mitigation:** Use more robust valve springs or reduce engine RPMs.  

<p align="center">
  
</p>

### Cam–Follower Contact Wear (Pitting / Scuffing)
High contact stresses between the cam lobe and follower or rocker interface can lead to surface fatigue, pitting, or scuffing, especially under inadequate lubrication or high spring loads. This wear alters the cam profile over time, reducing effective valve lift and changing valve timing. In severe cases, material loss can accelerate further wear and lead to catastrophic valvetrain failure.  

**Mitigation:** Use proper surface hardening (e.g., nitriding or carburizing), ensure adequate lubrication, and limit contact stresses through appropriate spring rates and follower geometry.  

<p align="center">
  
</p>

### General Wear
Continuous motion and contact cause material wear, degrading valve profiles and system performance over time.  

**Mitigation:** Perform routine maintenance, including lifter cleaning and lubrication.  

<p align="center">
  
</p>

---

## Critical Design Parameters

The following components and their measured dimensions will guide Phase 2 design and analysis. These are the critical geometric and material parameters that will determine tolerances, forces, and clearances in the system.

---

### Geometry that Controls Motion

#### Cam
<p align="center">
  
</p>
- Base circle, max lift, lobe ramp shape, and gear length/diameter.  
- Drives: valve lift curve, peak acceleration, contact loading.  
- Ensures precise cam timing and correct valve actuation.

#### Rocker
<p align="center">
  
</p>
- Pivot location, lever arm lengths, pad radii.  
- Drives: exhaust valve lift scaling, bending stress, tip contact stress.  
- Ensures alignment and proper force transmission.

#### Valves
<p align="center">
  
</p>
- Intake valve: stem diameter, head diameter, overall length.  
- Exhaust valve: stem diameter, head diameter, overall length.  
- Drives: packaging, valve mass/inertia, alignment, side loading.  
- Ensures proper lift, dwell, and seating without interference.

---

### Spring and Dynamic Inputs (for Failure Analysis)

#### Valve Springs
<p align="center">
  
</p>
- Intake and exhaust: free length, solid length, coil diameter, wire diameter.  
- Drives: seating force, valve-float margin, peak forces on components.  
- Ensures fatigue resistance and proper operation at high RPMs.

#### Operating Speed and Moving Mass
- Target cam speed and RPM, follower, rocker, and valve effective mass.  
- Drives: inertia loads (F=ma), fatigue-like cycling risk.  
- Needed for proper Phase 2 analysis of forces and clearances.

---

### Print-Driven Design Constraints
- **Material & process:** resin or filament printing, wall thickness, infill, minimum feature size.  
  - Drives: part strength, layer-line failure, creep, durability.  
- **Critical fits & clearances:** valve lash, stem-guide clearance, rocker pivot clearance, cam bore/bearing fits.  
  - Drives: binding vs. impact loads, timing accuracy, wear rate.  
- **Packaging & clearance envelope:** full-motion interference check across max lift and rocker sweep.  
  - Drives: collision prevention, assembly feasibility.  

> These constraints, combined with the measured dimensions above, ensure printed parts fit correctly, function as modeled, and provide all necessary parameters for Phase 2 design.

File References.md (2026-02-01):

# References
https://study.madeeasy.in/me/theory-of-machines/cam-nomenclature

https://racetech.com/ip-engine-topendrebuild-16-crf250r/

https://mxlocker.com/product/crf250r-cylinder-head-complete-hpd-cam-valves-gieco-honda-ra-SyYFA

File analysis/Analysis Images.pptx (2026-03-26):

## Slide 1

y

z

x

T

R_(Ay)

R_(Az)

F_(Chain)

T_(Spring)

R_(By)

T_(Spring)

F_(Spring)

R_(Bz)

F_(Rocker)

F_(Spring)

A

B

C

D

F

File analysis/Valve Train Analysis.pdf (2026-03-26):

## Static Stress Analysis

Camshaft

Material Properties
8620 Steel Per ASTM A29
σult≔530 MPa | Ultimate Tensile Strength
σyield≔385 MPa | Yield Tensile Strength
E≔200 | GPa | Modulus of Elasticity
G≔GPa | Modulus of Rigidity
ν≔0.30 | | Poisson's Ratio

Free Body Diagram


Dimensions
L≔118 mm
d≔17 mm
A≔29 mm
B≔41.66 mm | I≔π⋅―=

d

4
64

⎛⎝4.1 ⋅ 10³ ⎞
⎠ mm⁴
C≔59.9 mm
D≔77.09 mm
F≔90 mm | J≔2 I=⎛⎝8.2 ⋅ 10³ ⎞
⎠ | mm⁴

FOpen≔668 N; FClosed≔223 N; RockerMA≔―――=; 1.6 Mechanical Advantage from Rocker Arm; FRocker≔――――=; 2 ⋅FSpring RockerMA; Force Applied on Camshaft; From Rocker Arm; rCamLobe≔15 mm; TCam ≔⎛⎝2 ⋅FSpring⎞ ⎠; ⋅ rCamLobe=20.04 N ⋅m; rGear≔――――=; FChain≔-――=; TCam; rGear; Guess Values Constraints Solver; RAy≔1 N; RBy≔1 N; 2 ⋅FSpring+FChain-RAy-RBy＝0; -⎛⎝RAy ⋅A⎞; ⎠+⎛⎝FSpring ⋅B⎞; ⎠+⎛⎝FSpring ⋅ D⎞; ⎠-⎛⎝RBy ⋅F⎞ ⎠＝0; RAy; RBy; find ⎛⎝RAy ,RBy⎞ ⎠; RAy=-168.048 N; RBy=935.538 N

FSpring≔FOpen=668 N | Force of Spring at Max Open Length

Solving for Reaction Forces at Bearing Locations in Y-Direction

RAz≔1 N; RBz≔1 N; RAz+RBz-FRocker＝0; ⎛⎝FRocker ⋅ ((C-A))⎞; ⎠-⎛⎝RBz ⋅ ((F-A))⎞ ⎠＝0; RAz; RBz; find ⎛⎝RAz ,RBz⎞ ⎠; RAz=412.025 N; RBz=422.975 N; Shear and Moment Diagrams XY-Plane

Solving for Reaction Forces at Bearing Locations in Z-Direction Guess Values Constraints Solver

Mz_C≔MMax_z-⎛⎝FChain-RAy+FSpring⎞ ⎠; Shear and Moment Diagrams XZ-Plane; My_B≔RAz ⋅ ((B-A))=⎛⎝5.216 ⋅ 10³ ⎞ ⎠ N ⋅mm; Determining Critical Cross-Section; ⎛⎝MMax_z; ⎛⎝MMax_y; MomentMax≔max⎛⎝MR_B ,MR_C⎞

MMax_z≔21556.67 N ⋅mm | Max Moment in z occurs at B
MMax_y≔12731.56 N ⋅mm | Max Moment in y occurs at C

Critical Cross-Section is located at Point B

Determining Stresses; σbend≔―――――――=; MomentMax ⋅ 0.5 ⋅d I; 45.982 MPa; TCam ⋅ 0.5 ⋅d J; 20.774 MPa; τmax≔――⋅; ⎝MomentMax⎞ ⎠; 2 ⎛⎝TCam⎞ ⎠; 2 30.986 MPa; σvm ≔; bend; 2 58.387 MPa; Safety Factor; FSyield≔――=; σyield; σvm; 6.594 FSult≔――=; σult

Bearing PN: SKF 7203 BEP; Basic Dynamic Load Rating; Basic Static Load Rating; Fatigue Load Limit; RPMmax≔20000 rpm; Max RPM; Radial Load Factor; Axial Load Factor; Limiting Factor; Exponent of the Life Equation; aSKF≔25; Life Modification Factor (Best Estimate); rpm; captured in the Reaction forces above.; Fbearing_A≔; 2 RAz; Fbearing_F≔; 2 RBz; Fbearing_max≔max⎛⎝Fbearing_A ,Fbearing_F⎞; Max Radial Load; Faxial≔Fbearing_max=⎛⎝1.027 ⋅ 10³ ⎞; Axial Load; ⋅Fbearing_max+Y0; ⋅Fbearing_max=626.295 N; Equivalent Static Bearing Load; 8.782 Bearing Static Safety Factor

Bearing Safety Factor | (Assuming an axial load equal to the radial load)
a1≔0.64 | Life Adjustment Factor at 95% Reliability

Bearings are located at locations A and F, the loads on the bearings are

Fatigue Analysis Camshaft; Values from Static Analysis; σbend=45.982 MPa; mm⁴; σvm =58.387 MPa; τ=20.774 MPa; Assumptions; -Fully Reversing Bending (More Conservative); bend; 0 45.982 MPa; Alternating Stress; 35.982 MPa; Mean Stress; Se≔0.4 ⋅σult=212 MPa; Endurance Limit; Fatigue Factor of Safety; (Shigley's Table 6-8); σult σ'm; ⋅ ult; Results; high RPM engine operation.

-Shaft Continuously Rotating and Always Same Direction

Although analysis was performed statically, the large safety factor margins of both fatigue and yield stress for the camshaft provide confidence in the addition of dynamic loading caused by

Fatigue Analysis Valve Spring; Material Properties; A≔1974 MPa ⋅mmm; σult≔――=; ⎠ MPa; (Shigley's Table 10-4); τmax≔―⋅; σult; τupper≔KB ⋅――――=; 8 ⋅FOpen ⋅ D π⋅d; ⎛⎝1.465 ⋅ 10³ ⎞ ⎠ MPa; τlower≔KB ⋅――――=; 8 ⋅FClosed ⋅ D π⋅d; 489.073 MPa; τupper+τlower 2; 977.05 MPa; Mean stress; τupper-τlower 2; 487.977 MPa; Average Stress; Su≔τmax=⎛⎝1.169 ⋅ 10³ ⎞ ⎠ MPa; Se≔0.4 ⋅Su=467.506 MPa; 0.532 Fatigue Factor of Safety

Chromium-Silicon Alloy Steel Wire Per ASTM A401

Results

Since the fatigue factor of safety is less than 1, we can expect the spring to fail with the given parameters. Since the torsional stress in wire coil springs is highly dependent on the wire diameter, we will solve for a needed wire diameter to satisfy a fatigue safety factor of 2, however, I will not take into account the calculation of the ultimate strength due to its dependence on d, which will lower the safety factor from the requirement. Iterations will be performed to achieve FOS=2.

d≔

3
――――――――――――――

4 ⋅KB ⋅ D ⋅

⎛
⎜
⎝

―――――+

FOpen-FClosed
Se

―――――

FOpen+FClosed
Su

⎞
⎟
⎠
0.5 ⋅π
d=4.665 mm | Calculated wire diameter
d≔5 | mm | Iterative wire diameter

Verification

σult≔――=

A
d

m

| ⎛⎝1.659 ⋅ 10³ ⎞
⎠ MPa | (Shigley's Table 10-4)
τmax≔―⋅ | =

2
3
σult | ⎛⎝1.106 ⋅ 10³ ⎞
| | ⎠ MPa

D≔19 mm

C≔―=

D
d

3.8

KB≔―――=

4 ⋅C+2
4 ⋅C-3

1.41

τupper≔KB ⋅――――=

| 8 ⋅FOpen ⋅ D π⋅d

3

| | 364.526 MPa

τlower≔KB ⋅――――=

| 8 ⋅FClosed ⋅ D π⋅d

3

| | 121.691 MPa

τm ≔―――――=

τupper+τlower
| 2
243.108 MPa | Mean stress

τupper-τlower 2; 121.418 MPa; Average Stress; Su≔τmax=⎛⎝1.106 ⋅ 10³ ⎞ ⎠ MPa; Se≔0.4 ⋅Su=442.412 MPa; 2.023 Fatigue Factor of Safety

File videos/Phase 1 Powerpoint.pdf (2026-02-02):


# Phase 1: System Understanding & Conceptual Design

Group Members:

J Cosby, Zachary Montero, Maddox Lato, Zach Mitan, Nigel Sebastian, Joel Montoya


# Executive Summary

- Examines a Unicam style overhead cam valve train
- Identifies system function, components and potential failure modes
- Critical system in a four-stroke engine


# Four-Stroke Engine Overview

1. Intake Stroke - Intake valve opens, piston moves down, drawing in the air-fuel mixture.

### 2. Compression Stroke - Both valves are

closed, piston moves up, compressing the air-fuel mixture.

### 3. Combustion Stroke - Spark plug

ignites the compressed mixture, forcing the piston downward and generating torque on the crankshaft.

4. Exhaust Stroke - Exhaust valve opens, piston moves up again, pushing exhaust gases out of the cylinder.


# System Function

- Converts crankshaft rotation into valve motion
- Controls valve lift, timing, and seating
- Camshaft actuates intake valves directly, while exhaust valves are actuated via rocker arm
- Use of a single camshaft reduces rotating mass


# Major Components

- Cylinder Head
- Camshaft
- Rocker
- Valves
- Valve Springs
- Valve Buckets
- Cam Bearings
- Cam Chain


# Kinematics

- The camshaft geometry controls the valve motion
- Intake Valves:
- Lvalve = Lcamsℎaft
- Where: L = Lift
- Exhaust Valves:
- Lvalve = R ∗ Lcamsℎaft
- Where: R = Rocker Ratio
- Ratio of rocker arm lever lengths
- The camshaft completes one revolution per 2 revolutions of the crankshaft
- ωcamsℎaft =

1
2

ωcranksℎaft


# Failure Modes


- Spring Fatigue – Loss of closing force, can lead to fracture
- Valve Float – Loss of contact with cam, generally occurs at high RPM. Can cause valve to contact piston.
- Cam Lobe / Follower Contact Fatigue – Pitting, spalling or scuffing of the cam lobes or followers, can affect the cam profile.


# Critical Design Parameters


- Camshaft Geometry – Base circle, lobe shape, gear diameter
- Rocker Geometry – Pivot location, lever arm lengths


- Valve Geometry – Head diameter, overall length
- Springs – Wire diameter, free length

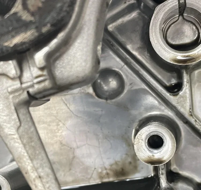
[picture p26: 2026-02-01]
figures/Cracked_Block.png

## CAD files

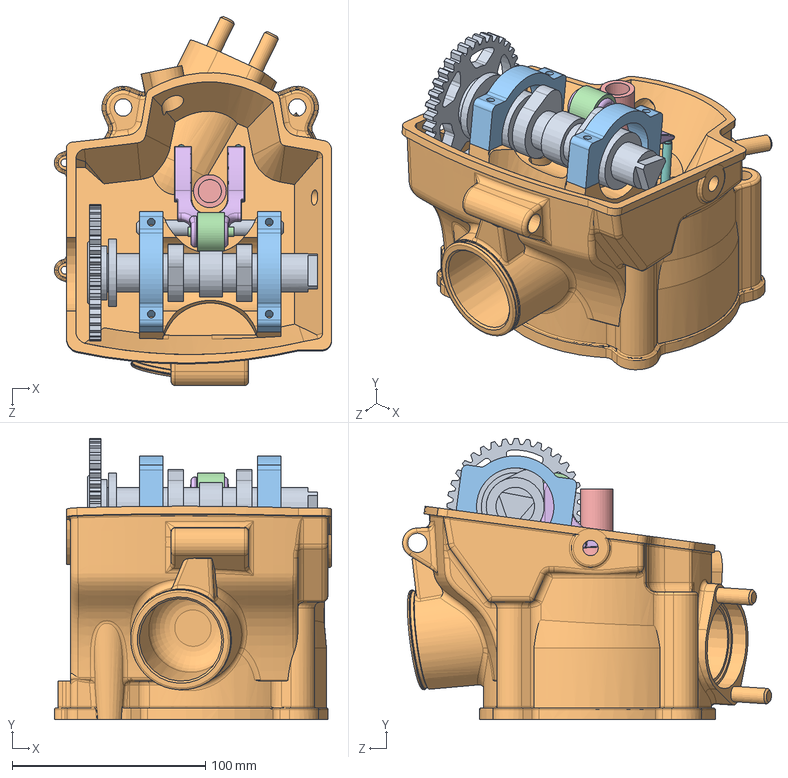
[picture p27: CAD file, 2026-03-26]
cad/Valve Train Assembly.SLDASM
143.4 x 145.4 x 190.8 mm
Cylinder Head 2.0
Camshaft
Exhaust Valve x 2
Intake Valve x 2
Rocker
Sleeve
Rocker Roller
Camshaft Top Mount x 2
Intake Valve Bucket x 2
Rocker Mount Pin

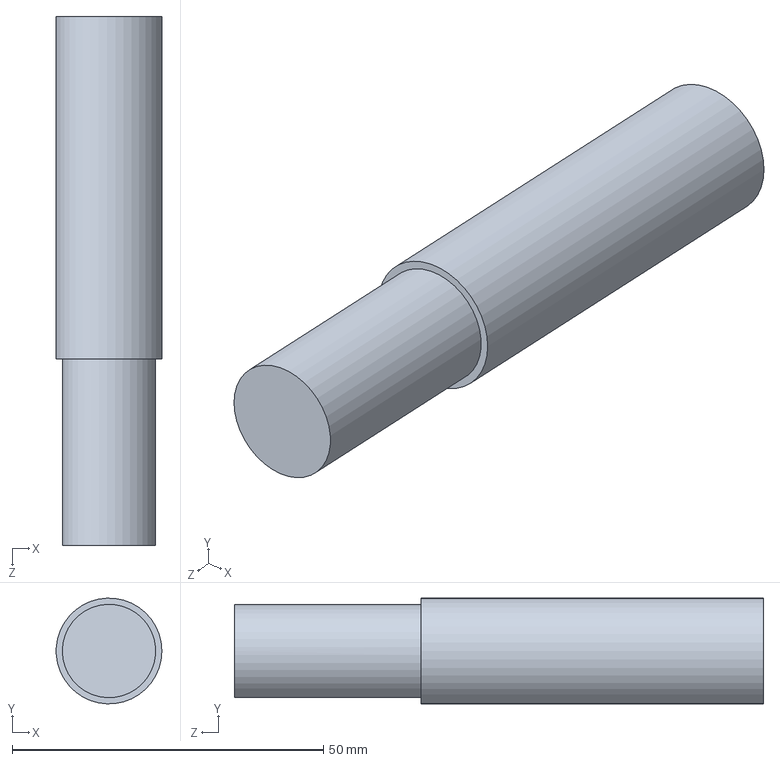
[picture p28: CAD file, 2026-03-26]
cad/Sleeve.SLDPRT
17.0 x 17.0 x 85.0 mm

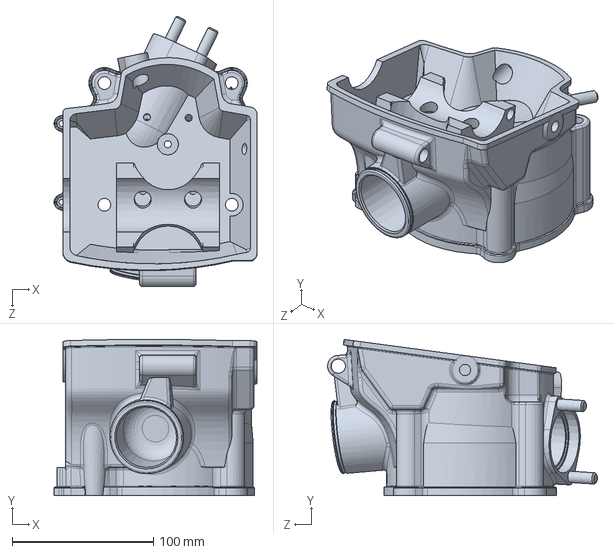
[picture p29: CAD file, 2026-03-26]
cad/Cylinder Head 2.0.SLDPRT
143.4 x 110.4 x 190.8 mm

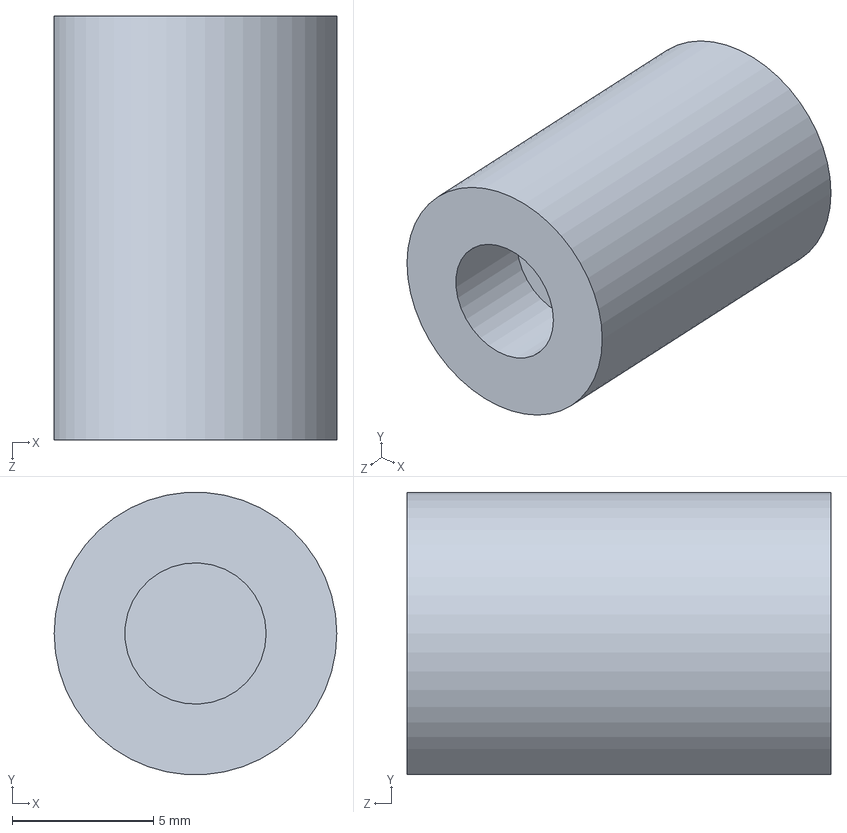
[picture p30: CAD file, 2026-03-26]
cad/Intake Valve Bucket.SLDPRT
10.0 x 9.98 x 15.0 mm

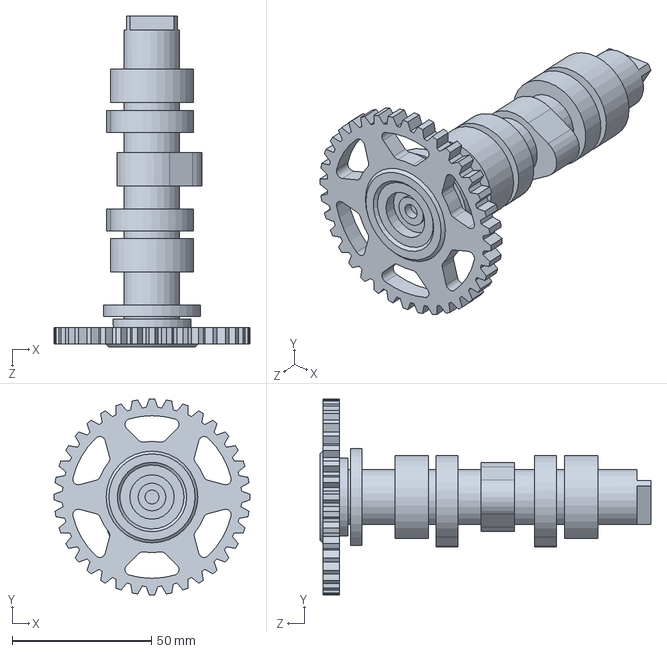
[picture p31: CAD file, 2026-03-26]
cad/Camshaft.SLDPRT
70.5 x 70.5 x 119.0 mm

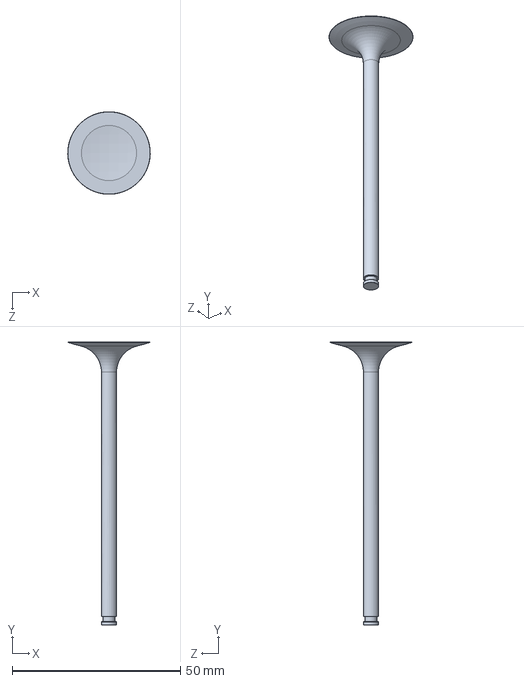
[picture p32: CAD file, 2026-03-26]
cad/Exhaust Valve.SLDPRT
24.5 x 84.1 x 24.5 mm

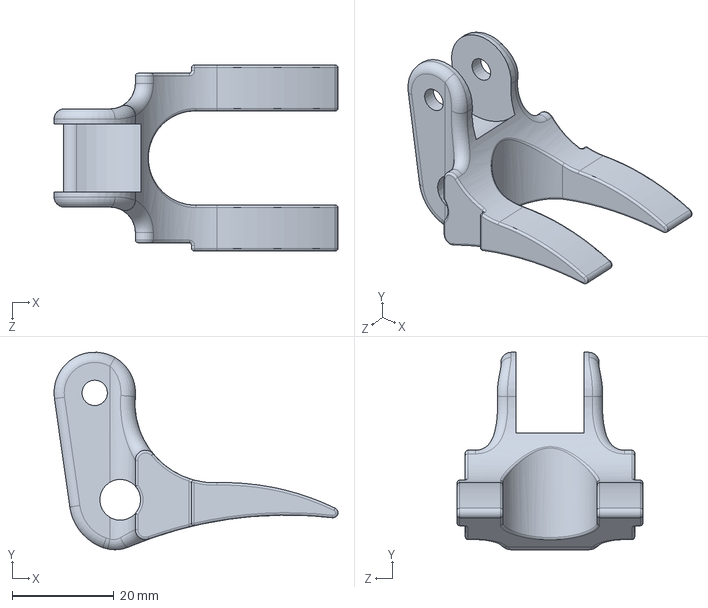
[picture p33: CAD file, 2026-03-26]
cad/Rocker.SLDPRT
55.8 x 38.8 x 36.5 mm

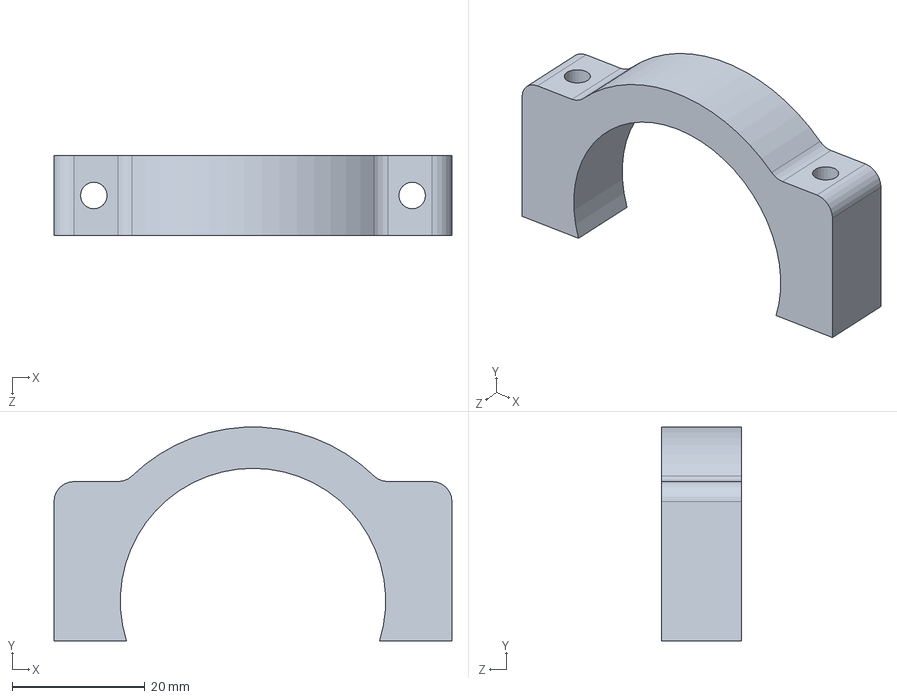
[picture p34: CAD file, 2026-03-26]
cad/Camshaft Top Mount.SLDPRT
60.0 x 32.2 x 12.0 mm

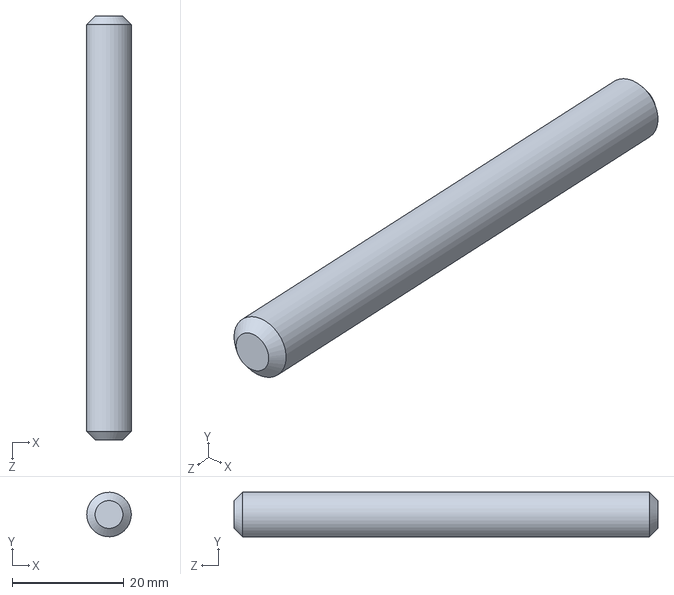
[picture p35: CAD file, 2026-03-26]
cad/Rocker Mount Pin.SLDPRT
8.00 x 7.99 x 76.0 mm

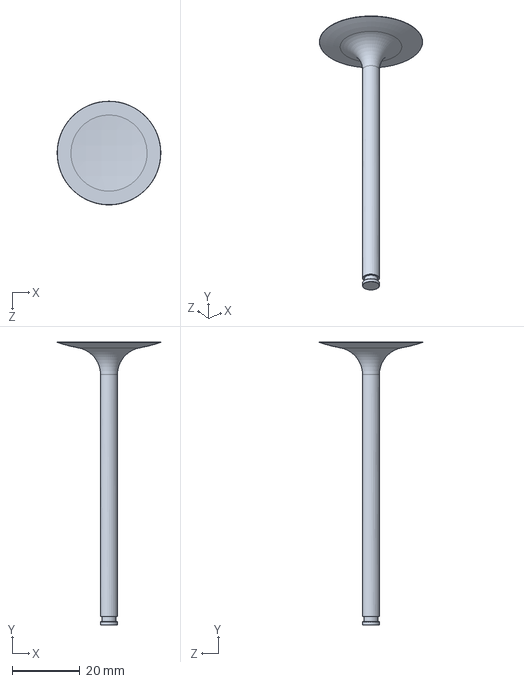
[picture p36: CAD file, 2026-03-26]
cad/Intake Valve.SLDPRT
30.5 x 83.3 x 30.5 mm

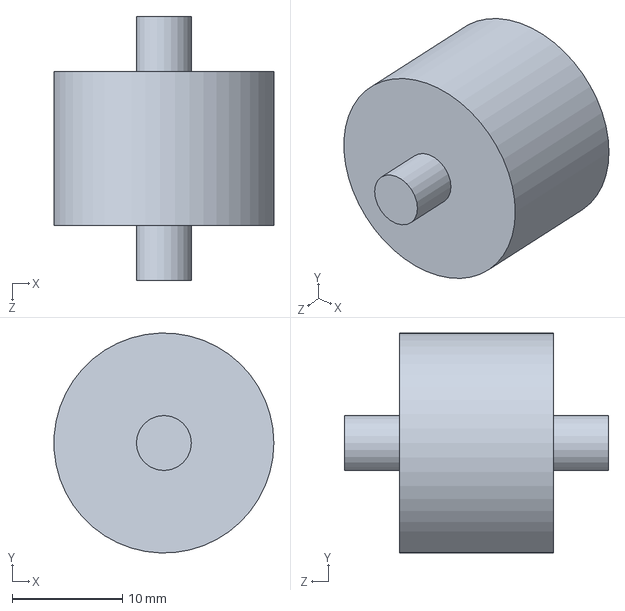
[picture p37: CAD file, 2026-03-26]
cad/Rocker Roller.SLDPRT
20.0 x 20.0 x 24.0 mm

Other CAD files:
drawings/Camshaft Top Mount.SLDDRW
drawings/Camshaft.SLDDRW
drawings/Exhaust Valve.SLDDRW
drawings/Intake Valve Bucket.SLDDRW
drawings/Rocker Mount Pin.SLDDRW
drawings/Rocker Roller.SLDDRW
drawings/Rocker.SLDDRW
drawings/Sleeve.SLDDRW

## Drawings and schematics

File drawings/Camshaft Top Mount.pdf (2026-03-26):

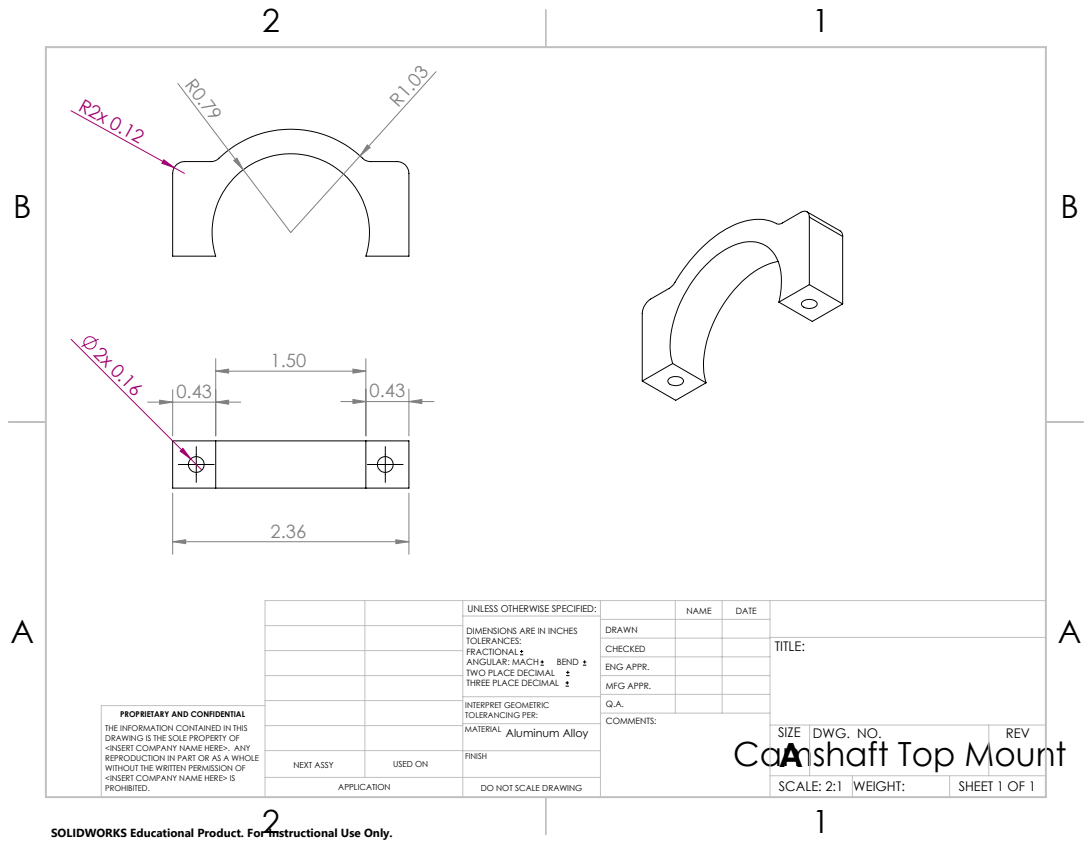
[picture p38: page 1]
Camshaft Top Mount

UNLESS OTHERWISE SPECIFIED: | | NAME | DATE
DIMENSIONS ARE IN INCHES TOLERANCES: FRACTIONAL ANGULAR: MACH BEND TWO PLACE DECIMAL THREE PLACE DECIMAL | DRAWN

CHECKED | | | TITLE:

ENG APPR.
MFG APPR.

INTERPRET GEOMETRIC TOLERANCING PER: | Q.A.
MATERIAL Aluminum Alloy | | SIZE A | DWG. NO. | REV

PROPRIETARY AND CONFIDENTIAL
THE INFORMATION CONTAINED IN THIS
DRAWING IS THE SOLE PROPERTY OF
<INSERT COMPANY NAME HERE>. ANY
REPRODUCTION IN PART OR AS A WHOLE
WITHOUT THE WRITTEN PERMISSION OF
<INSERT COMPANY NAME HERE> IS
PROHIBITED.

NEXT ASSY | USED ON | FINISH

APPLICATION | DO NOT SCALE DRAWING | | SCALE: 2:1 | WEIGHT: | SHEET 1 OF 1

SOLIDWORKS Educational Product. For Instructional Use Only.
